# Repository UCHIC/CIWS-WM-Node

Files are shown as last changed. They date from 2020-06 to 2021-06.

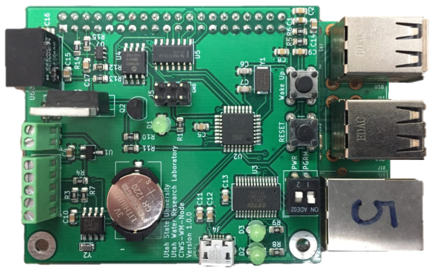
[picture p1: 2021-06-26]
Hardware/PCB_Design/DevicePicturePCB.png

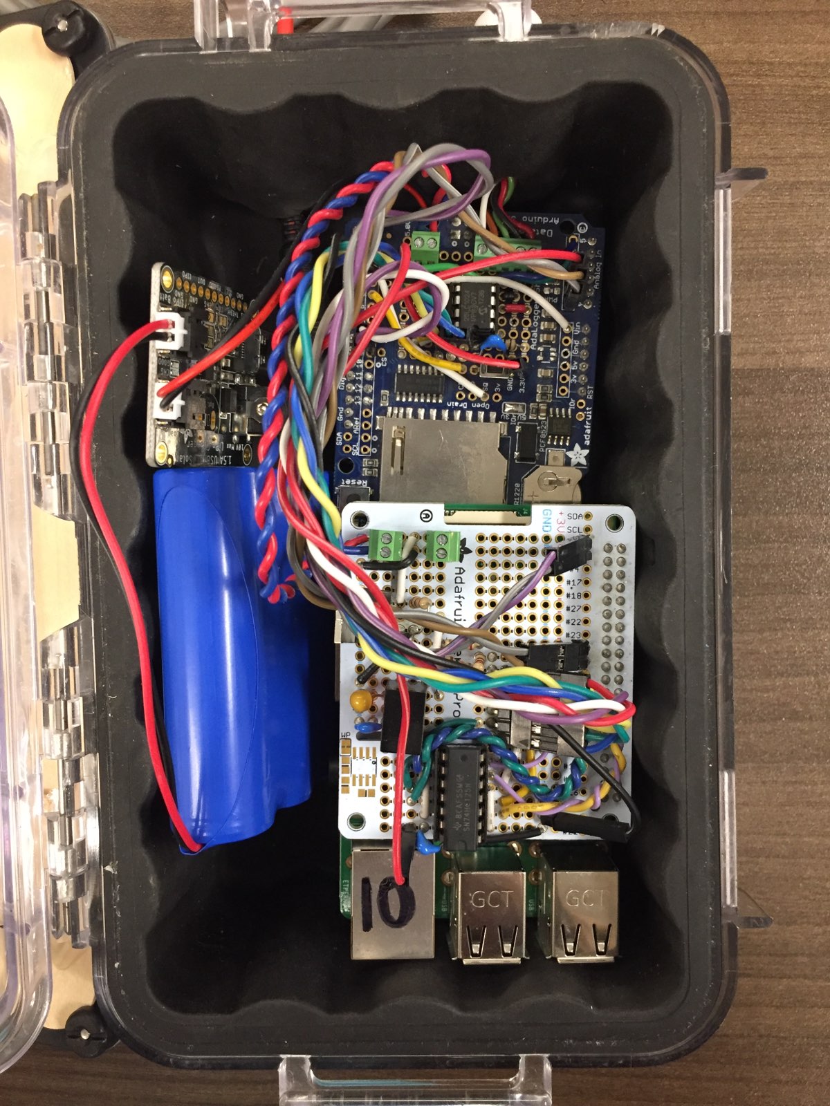
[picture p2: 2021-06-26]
Hardware/Off-The-Shelf/DevicePicturePrototype.jpg

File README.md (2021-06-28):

# CIWS-WM-Node

This repository contains hardware and software designs for a computationally-enabled water meter datalogger. The hardware is made up of two parts. One part is a Raspberry Pi single board computer that serves as the computational resource. The Raspberry Pi is coupled with a data acquisition device that is based on an Arduino Pro and is similar to our simplified datalogger for magnetically-driven residential water meters (See [UCHIC/CIWS-MWM-Logger](https://github.com/UCHIC/CIWS-MWM-Logger)).

The data acquisition device is primarily responsible for processing magnetometer sensor data and storing flow data from the water meter. Secondarily, it controls power to the Raspberry Pi in order to conserve battery life and reduce overall power consumption. Once powered, the Raspberry Pi retreives the flow data and processes it to compute useful summaries of water use, identify water end-uses, or execute other user-defined computational code.

## Structure of this Repository

The 'Firmware' directory contains the firmware for the microcontroller-based data acquisition device, or Datalogger.

The 'Software' directory contains the software for the Raspberry Pi.

The 'Hardware' directory contains hardware design information, including a design and instructions for assembling a Node from off-the-shelf components as well as a printed circuit board (PCB) design and instructions for manufacturing them.

The 'Docs' directory contains documentation.

This device is still under active development.

## Cyberinfrastructure for Intelligent Water Supply (CIWS) 

CIWS is a project funded by the U.S. National Science Foundation to develop cyberinfrastructure for smart water metering and high resolution water-use data collection. We are developing systems for high resolution residential water consumption data collection, processing, and analysis.

## Sponsors and Credits


This work was supported by National Science Foundation Grant [CBET 1552444](https://www.nsf.gov/awardsearch/showAward?AWD_ID=1552444). Any opinions, findings, and conclusions or recommendations expressed in this material are those of the author(s) and do not necessarily reflect the views of the National Science Foundation.

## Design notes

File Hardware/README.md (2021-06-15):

# WM-Node Hardware

This directory contains design files pertaining to the WM-Node datalogging device separated into two directories.

## PCB Design
The directory PCB_Design contains design files in KiCad for a printed circuit board which hosts all of the required components to transform a Raspberry Pi into a WM-Node device. The design files are generated using KiCad 5.

## Off-the-shelf Parts
The directory off-the-shelf parts contains a list of all the parts necessary to create a computaional node using off the shelf parts. This directory also contains instructions and diagrams for contructing the computational node.

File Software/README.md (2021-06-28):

## Instructions for Configuring a Raspberry Pi

NOTE: Only the Raspberry Pi 3 Model B V1.2 has been verified to work, although newer models should work as well.

1. Connect your Raspberry Pi to the internet. 
2. Type `sudo apt-get update` into the command line and hit enter. This updates software packages available on your pi.
3. Type `sudo apt-get install git` into the command line and hit enter. This installs git onto your pi.
4. Type `git clone https://github.com/UCHIC/CIWS-WM-Node.git` into the command line and hit enter. Using git, this clones this repository onto your pi.
5. Type `mv CIWS-WM-NODE/Software/ Software` into the command line and hit enter. This moves the Software directory into your home directory.
6. Type `cd Software` into the command line and hit enter. This changes the Software directory to your working directory.

From the `Software` directory, run the following commands:
```
chmod +x setup.sh
sudo ./setup.sh
```
At a minimum, be sure to `set-timer-resolution` before attempting to log.

You can now use the `Logger` module in Python. Note that this was built with Python 3.7.</br></br>
The following dependencies should be automatically installed by running `setup.sh` on the Raspberry Pi, assuming the Raspberry Pi is connected to the internet.
```
python3-dev
python3-smbus
wiringpi
python3-requests
python3-pandas
python3-seaborn
pyhton3-sklearn
```

## Software Overview

Most of the Software functionality of the WM-Node device is described in the file `logger.c`. The C code is compiled as a Python module by the script `setup.sh`, and is used in the Python scripts in this directory.

### Files:
- `LoggerAutoRun.py`: Runs on every power up.
- `LoggerShell_CLI.py`: User interfaces for the datalogger.
- `piHandler.py`: Handles the functions primarily used by the pi.
- `arduinoHandler.py`: Handles functions used to commmunicate with arduino.
- `README.md`: This file.
- `bashrc`: Configuration file for the Raspberry Pi.
- `cmdline.txt`: Configuration file for the Raspberry Pi.
- `config.txt`: Configuration file for the Raspberry Pi.
- `logger.c`: Defines all of the functions use in the `Logger*` python scripts.
- `rc.local`: Configuration file for the Raspberry Pi.
- `setup.py`: Builds Python module Logger from `logger.c`.
- `setup.sh`: Sets up Raspberry Pi device using the files in this directory.
- `uuidcopy.c`: Copies the value for the field `root=PARTUUID=` from the original `cmdline.txt` and stores it in the new `cmdline.txt`.

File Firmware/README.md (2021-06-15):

This folder contains the source code for the firmware running on the ATmega328p microcontroller in the folder `Computational_Firmware`. It was developed using Arduino IDE version 1.8.9, though there are very few actual Arduino Libraries used (in order to save on performance).

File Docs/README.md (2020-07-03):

# Documentation
This directory contains documents describing the hardware, software, and firmware of the CIWS-WM-Node datalogging device.
## Hardware
The hardware documentation covers the basic system architecture and functional overview. Electrical diagrams and hardware design files are located in the `Hardware` directory.
## Firmware
The firmware documentation covers the code written for the AVR microcontroller portion of the device.
## Software
The software documentation covers the code written for the Raspberry Pi embedded computer connected to the device.

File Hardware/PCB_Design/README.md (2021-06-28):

# Manufacturing
This folder contains all the files necessary for manufacturing a printed circuit board (PCB) version of the CIWS-WM-Node. The PCB contains everything needed to interface with a Raspberry Pi computer and magnetometer sensor to collect and process data.

The `.pro` and `.sch` files are the board layout and schematic respectively. Use these two files with the `.kicad_pcb` file to view the design in kicad.

The `.csv` file and `.zip` files are used for manufaturing the devices. The `.zip` file contains the drill file, gerber files, assembly drawings, and position files. The `.csv` is a list of components used on the device. 

# Instructions for setting up the PCB After Manufacture

1. Remove the jumper on the `EEPROM Power` pins.
2. Connect the micro usb port on the PCB to your computer using a USB cable and turn the `PWR` switch on the PCB ON.
3. Connect your computer to the 6 header pins on the PCB with an AVR in-system programmer (ISP). Make sure to plug in the ribbon cable the right direction. A suitable AVR ISP is referenced in the link below.
4. Open up the code in the `Firmware` directory from this repository using the Arduino IDE and click on `Tools`. Select `Arduino Pro or Pro mini` as the board, `Atmega328P (3.3V 8MHZ)` as the processor, and `AVR ISP` as the programmer.
5. While still in the Arduino IDE, click `Burn Bootloader`. Wait for it to finish.
6. Unplug the AVR ISP from the PCB and turn the `PGRM` switch on the PCB ON.
7. In the `Tools` menu of the Arduino IDE, select the serial port connected to the micro usb port. If you are unsure which one is correct you can unplug the USB cable and see which one disappears. Reconnect the USB cable and select that one.
8. In the Arduino IDE, click `Upload`. This unploads the code onto the ATMEGA328P chip.
9. Turn the `PWR` and `PRGM` switches off on the PCB. 
10. Put the jumper back on the `EEPROM Power` pins on the PCB. 

Once these steps are complete, the PCB is ready to be snapped onto the header of a Raspberry Pi for use.

A suitable AVR ISP: https://www.pololu.com/product/3172

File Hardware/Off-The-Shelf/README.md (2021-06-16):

# Off-the-shelf Parts

This directory contains files describing the construction of a WM-Node device using off-the-shelf parts obtainable from electronics suppliers such as Mouser, Sparkfun, and Adafruit.

The BuildInstructions.txt file gives instructions for setting up the adafruit datalogger shield. 

PrototypeWiringGuide.png gives a diagram for how to wire the pi and arduino together.

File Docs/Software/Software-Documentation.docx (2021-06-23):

CIWS-WM-Node Datalogger

Software Documentation

Software ver. 1.0.0

# Project Organization

  The CIWS-WM-Node software is comprised of the following files:
- LoggerAutoRun.py
- arduinoHandler.py
- piHandler.py
- LoggerShell_CLI.py
- logger.c
- setup.py
- setup.sh

The functions which interact with the Raspberry Pi GPIO peripherals are written in C code in logger.c. Using Python's API (available from Python.h), these C functions are wrapped up as a Python module called Logger, which is used in arduinoHandler.py. The software can be set up on the Raspberry Pi by running setup.sh, which configures the Raspberry Pi and calls setup.py, which compiles logger.c.

arduinoHandler.py Is a wrapper module for logger.c. It handles the communication of the pi with the microcontroller and EEPROM. It also handles the initialization of the SPI, UART, and GPIO pins. Pins 24 and 25 on the raspberry pi are set by this module to indicate that the EEPROM is being read and that the pi is on respectively.

LoggerAutoRun.py is run automatically whenever the Raspberry Pi is powered on. It is responsible for retrieving data from the EEPROM. It will also shut down the Raspberry Pi if the data buffer is full or it is midnight (in other words, if it was not turned on by a user).

piHandler.py handles the functionality of the pi. This includes the storage and retrieval of settings data. It also handles the analysis, storage, and transmission of both raw data and data resulting from the computations of raw data.

As the previous paragraphs suggest, with the exception of LoggerAutoRun.py, these scripts are run by LoggerShell_CLI.py. In fact, users should not run any other script than LoggerShell_CLI.py, which is run automatically when the user logs in. This script provides a user interface as a 'shell' around the functionality of the datalogger.

# GPIO Functions: logger.c

The code in logger.c comprises the Logger module used in the other Python scripts. There are 9 functions in this file:

- init
- initPins
- bufferMax
- setRomBusy
- setPowerGood
- loadData
- reportSwap
- setRomFree
- setPowerOff

These functions mainly deal with GPIO and file I/O operations using the following libraries:

- wiringPi.h
- wiringPiSPI.h
- wiringSerial.h

The following sections describe the individual functions in this file.

## Initializing the Module: init()

The function init initializes the wiringPi GPIO library, the wiringPi SPI library, and the wiringPi Serial library. The SPI module is initialized to communicate at 2 MHz, and the Serial module is initialized to communicate at 9600 Baud.

## Initializing the GPIO pins: initPins()

This function sets up the initial values of the GPIO pins. There are two GPIO pins this function initializes:

- ROM_BUSY (Broadcom GPIO 24)
- POWER_GOOD (Broadcom GPIO 25)

ROM_BUSY and POWER_GOOD are both initialized as logic low (0 V).

## Read Maximum Buffer Size: bufferMax()

This function simply returns the variable BUFFER_MAX. This value determines the amount of data that the Raspberry Pi reads from the EEPROM chip.

## Request EEPROM: setRomBusy()

This function sets the ROM_BUSY pin HIGH, which tells the microcontroller that the Raspberry Pi is reading the EEPROM. The microcontroller yields the EEPROM in CERTAIN SITUATIONS:

1. The Raspberry Pi was just activated
2. The Raspberry Pi instructed the microcontroller to stop a logging session

The microcontroller will not honor this request in any other situations.

## Report Power On: setPowerGood()

This function sets the POWER_GOOD pin HIGH, which tells the microcontroller that the Raspberry Pi has successfully powered on.

## Read Data from EEPROM: loadData()

This function reads data from the EEPROM chip. The function allocates an array to hold the EEPROM data. The function then calls a SPI transaction, and data gets transferred from the EEPROM chip to the data array.

## Swap Report with Microcontroller: reportSwap()

    This function swaps "report" data with the Arduino. This data consists of the following:

Data Field (Bytes) | Name | Description
0 | Years | Current year
1 | Months | Current month
2 | Days | Current day
3 | Hours | Current hour
4 | Minutes | Current minute
5 | Seconds | Current second
6 | Previous Pulses | Pulses in the previous logging sample period
7 | Total Pulses 0 | Total pulses over logging session (byte 0)
8 | Total Pulses 1 | Total pulses over logging session (byte 1)
9 | Total Pulses 2 | Total pulses over logging session (byte 2)
10 | Logging | Boolean: Is the device logging or not?

The data swap is done over a serial UART bus. The data messages are interlaced; in other words, the Raspberry Pi sends one byte, and the Arduino sends the corresponding byte. The Raspberry Pi can overwrite the data by sending any data value other than 0xFF, or 255. 255 (0xFF) is used by the Raspberry Pi to read the data.

## Release EEPROM: setRomFree()

    This function simply sets the ROM_BUSY pin low, signaling to the Arduino that the Raspberry Pi has finished reading the EEPROM.

## Report Power Off: setPowerOff()

    This function sets the POWER_GOOD pin low, signaling to the Arduino that the Raspberry Pi is shutting down. The Arduino will cut power to the Raspberry Pi 12 seconds after receiving this information.

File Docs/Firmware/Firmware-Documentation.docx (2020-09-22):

CIWS-WM-Node Datalogger

Firmware Documentation

Firmware ver. 1.0.0

# Project Organization

  The CIWS-WM-Node Datalogger project is organized using the standard approach using header files and source files, applied to an Arduino IDE environment. For those unfamiliar, C/C++ code is separated into header files and source files. The following example aims to make it clear why this is the case.
  Consider the following C code:
  int main()
  {
  int a = 2;
    int b = a * 4;
    printf(“The result is %d\n”, b);
    int c = b * 4;
    printf(“The result is %d\n”, c);
    return 0;
  }
  Obviously, this is a trivial example to illustrate how much more complex code is handled in this project. This code can be much more modular (and readable) by introducing a function:
  int times4(int input)
  {
  return input * 4;
  }

int main()

{

int a = 2;

int b = times4(a);

printf(“The result is %d\n”, b);

int c = times4(b);

printf(“The result is %d\n”, c);

return 0;

}

The code is now more readable and modular, but now the main() function is at the bottom of the file (and it has to be, otherwise the function times4() would not be recognized in main(). Fortunately, programmers are good at finding ways around problems. The following code listing works just as well as the previous example:

  int times4(int input);

int main()

{

int a = 2;

int b = times4(a);

printf(“The result is %d\n”, b);

int c = times4(b);

printf(“The result is %d\n”, c);

return 0;

}

  int times4(int input)
  {
  return input * 4;
  }
  Now, the main() function is much closer to the top of the file, making it easy to find the program’s starting point. The main() function recognizes the times4() function because it’s declared above main() using what’s called a function prototype, while the rest of times4() is defined below main(). This works really well for a handful of functions, but defining every function in one file becomes a mess in a project like the CIWS-MWM firmware. To counter this, two new files are created: times4.h and times4.cpp. The function prototype goes in times4.h, and the function definition goes in times4.cpp, leaving the file containing main() nice and clean:
  #include “times4.h”

int main()

{

int a = 2;

int b = times4(a);

printf(“The result is %d\n”, b);

int c = times4(b);

printf(“The result is %d\n”, c);

return 0;

}

Again, though this example seems trivial, it is a very good way to organize a large firmware project like CIWS-MWM. The aim of this section was to illustrate why the project is organized the way it is.

# Main Loop: Computational_Firmware.ino

The file Computational_Firmware.ino is the program’s starting point. All Arduino projects have a .ino file. Ours contains four functions:

- void setup()
- void loop()
- void INT0_ISR()
- void INT1_ISR()

The functions setup() and void() in the .ino file are actually called in the following manner:

int main()

{
setup();

while(1)

{

loop();

}

}

This way, setup() is called once, and loop() is called repeatedly until the microcontroller is reset. A flowchart of this process is shown here:

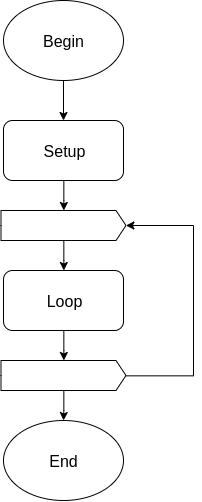
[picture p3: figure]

The setup() function does the following:

- Initializes the GPIO pins and peripherals
- Initializes the system state data structure
- Initializes the magnetometer
- Initializes the real-time clock
- Sets up the magnetometer and real-time clock interrupt handlers
- Stops the clock for all unused peripherals

A flow chart of the setup() function is shown on the next page.

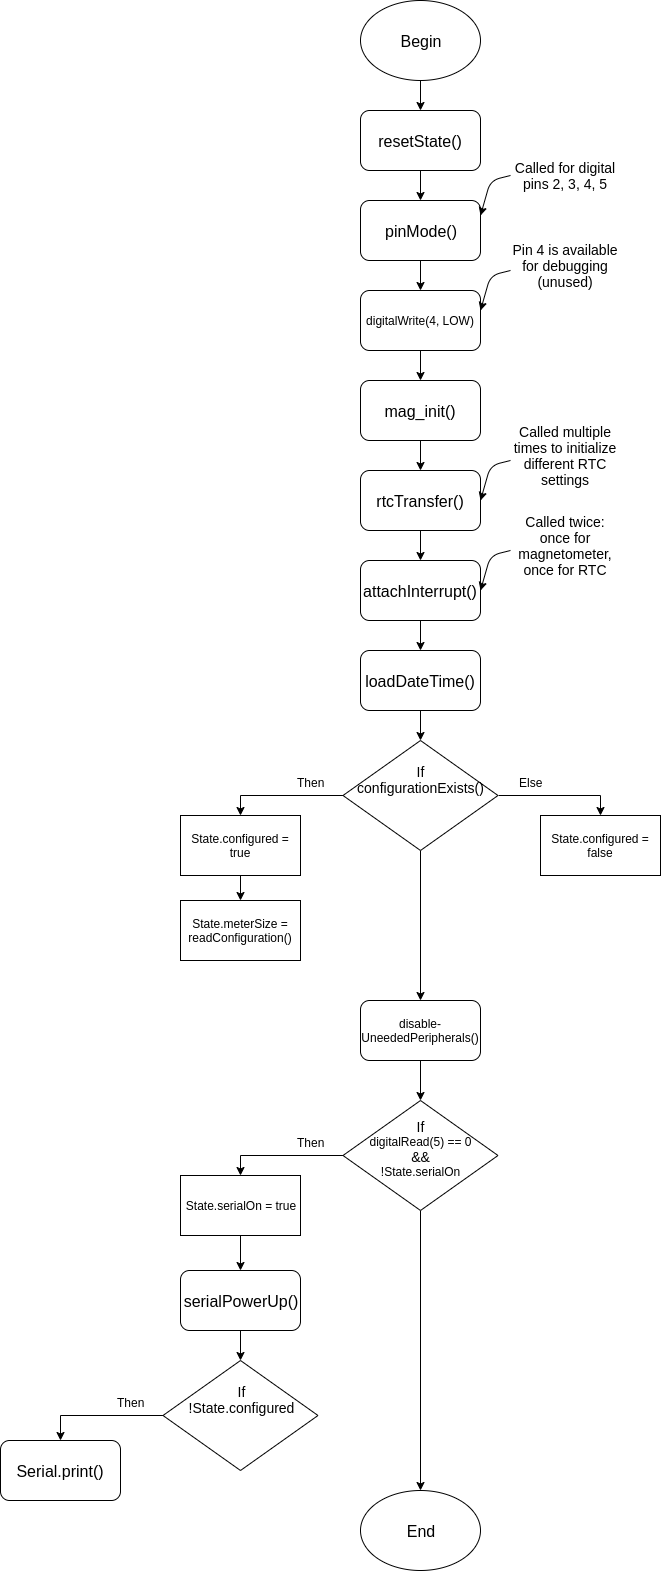
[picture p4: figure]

The loop() function is the datalogger firmware’s main loop, and performs the following actions:

1. Check if the Raspberry Pi should be activated
2. Run the serial communication between the datalogger and the Raspberry Pi
3. Monitor signals from the Raspberry Pi
4. Check if four seconds are up
5. Check if magnetometer data is ready
6. Process incoming data to count peaks

A flowchart of the loop() function is shown on the next page.

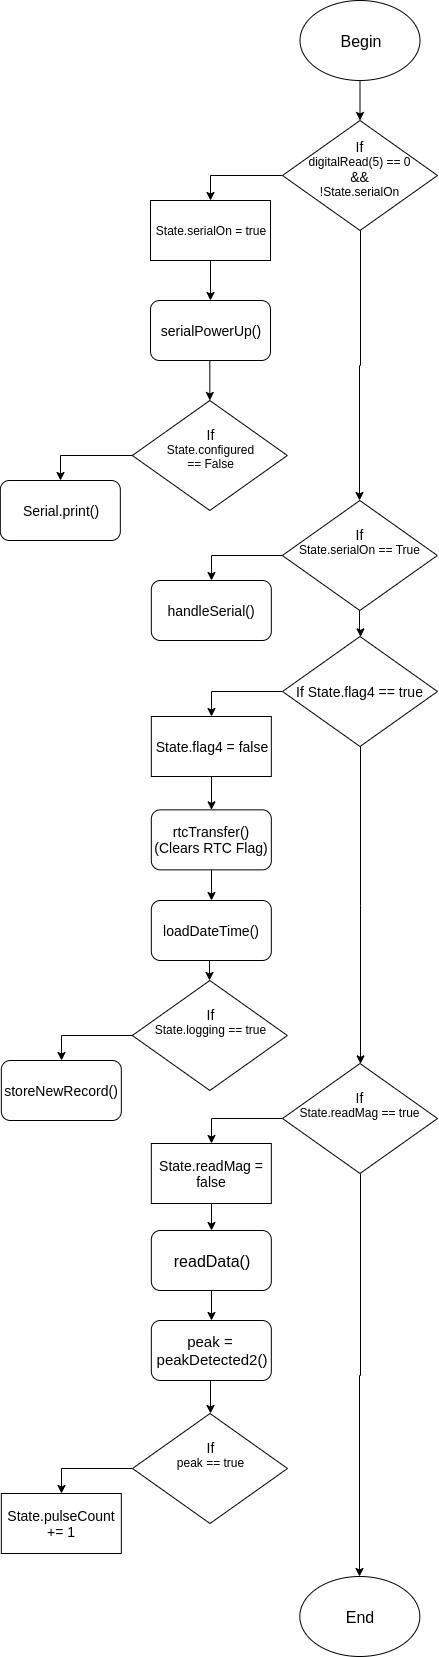
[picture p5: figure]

The functions INT0_ISR() and INT1_ISR() are both interrupt service routines. For those unfamiliar with interrupts, an interrupt service routine is a function executed when an event in hardware occurs. INT0_ISR() code executes when the voltage on digital pin 2 transitions from low to high, and INT1_ISR() code executes when the voltage on digital pin 3 transitions from high to low.

The voltage signal on digital pin 2 is controlled by the magnetometer. When the magnetometer has new data ready to report, it sets the voltage on pin 2 high, causing INT0_ISR() to execute.

The voltage signal on digital pin 3 is controlled by the real time clock. When four seconds have elapsed, the real time clock sets the voltage on pin 3 low, causing INT1_ISR() to execute.

Both interrupt service routines simply set a flag to true. The main loop checks these flags, and if they are set, responds accordingly. This is good practice; interrupt service routines need to be kept as short as possible.

# System State: state.h and state.cpp

  These files define two C/C++ structs, State and SignalState.
  State keeps track of several important values:
- byte pulseCount – The number of pulses in the current sample period.
- byte lastCount – The number of pulses in the previous sample period.
- unsigned int totalCount – The number of pulses since logging started.
- unsigned long recordNum – The record number of the current sample period.
- bool logging – Boolean flag: True if the device is logging, false if it is not.
- bool flag4 – Boolean flag: True if four seconds has passed, false if not.
- bool serialOn – Boolean flag: True if serial interface is active, false if it is not.
- bool SDin – Boolean flag: True if an SD card has been initialized, false if not.
- bool readMag – Boolean flag: True if magnetometer data is ready, false if it is not.
- char meterSize – Stores the meter size, used to compute water flow.
- bool configured – Boolean flag: True if valid configuration data exists in memory.
- char filename[13] – Stores the current filename.

This State struct is initialized using the function void resetState(volatile State_t* State). The pulse counts are initialized to zero, the record number is initialized to one, and the boolean flags are initialized to false.

SignalState keeps track of values used for processing the magnetometer signal. A few values are left over from an older signal processing algorithm. These are noted, and will be removed in a future release.

- float x[2] = {0, 0}; – Input signal from the magnetometer.
- float s = 0; - From old algorithm.
- float sf[2] = {0, 0}; - From old algorithm.
- float a = 0.95; - DC Removal filter pole.
- float y[2] = {0, 0}; - Output signal from DC Removal filter.
- float offset = -0.005; - From old algorithm.
- bool slopeWasPositive = false; - From old algorithm.
- bool slopeIsPositive = false; - From old algorithm.
- bool triggered = false; - Boolean flag for software-based schmitt trigger.

The use of these values is detailed in the next section, Peak Detection.

# Peak Detection: detectPeaks.h and detectPeaks.cpp

These files define the function bool peakDetected(volatile SignalState_t* signalState)

The function peakDetected() is responsible for detecting peaks corresponding to water flow in the signal read by the magnetometer. Before going over the code, it is crucial to understand the filtering algorithm implemented by the code.

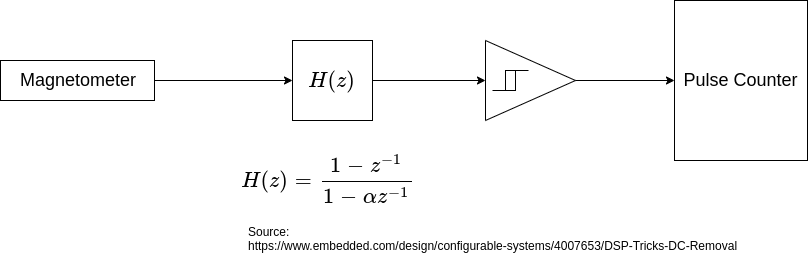
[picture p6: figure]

The function peakDetected() implements the two middle blocks of the above diagram. The block H(z) removes the signal’s DC offset. This centers the signal at zero, which permits a simple peak-detecting algorithm called a software schmitt trigger, the triangular block in the diagram.

The schmitt trigger watches for the signal to cross its high and low thresholds. When the signal crosses the high threshold, the schmitt trigger will count it as a peak, but will not count any other high-threshold crossing as a peak until the signal crosses the low threshold. This ensures that noise in the magnetometer’s signal cannot be counted as extra peaks. This peak detection is implemented in the following way:

Begin:

/** H(z) **/

y[n] = a * y[n - 1] + x[n] - x[n - 1]

/** Schmitt Trigger **/

If triggered:

If y[n] < -1:

triggered is false

If not triggered:

If y[1] > 1:

triggered is true

return peak = true

End

  A C/C++ struct called SignalState stores the current input sample (x[n]), the previous input sample (x[n - 1]), and the previous output sample (y[n – 1]). SignalState also holds a and triggered. Threshold values for the Schmitt Trigger are declared inside the function peakDetected(). This information is all that is necessary to detect if a peak is occurring in the magnetometer’s signal. SignalState is defined in the file state.h.
  The value a is the pole of H(z). For this filter, it is desirable for the pole to be close to, but not equal to, one. For any digital filter, a pole greater than or equal to one causes instability.

This function is only called once every time a data sample is collected from the magnetometer.

# Magnetometer: magnetometer.h and magnetometer.cpp

The following functions are defined in magnetometer.cpp and magnetometer.h:

1. bool mag_init()
2. void read_mag(int8_t* data)
3. void mag_transfer(int8_t* data, uint8_t reg, uint8_t numBytes, uint8_t RW)
4. readData(volatile SignalState_t* SignalState)
5. initializeData(volatile SignalState_t* SignalState)

These functions are responsible for the initialization and reading of an LIS3MDL magnetometer. Above, they are listed in order of appearance, but in the following sections, they will be covered in order from low-level to high-level functionality.

The function mag_transfer() takes an array of data, a register number, the length of the array of data, and a read/write flag as input, and is responsible for writing data and reading data to and from the magnetometer. Most of the time, data will be read from the magnetometer, but data does get written to the magnetometer when initialized on startup. The data is read and written via an I²C serial bus, and the Arduino IDE’s Wire library is used for I²C communication.

The function mag_init() does not take any input, and is responsible for initializing the magnetometer when the datalogger is started up. It utilizes the function mag_transfer() to write initialization data to the magnetometer. The following table lists the data written to each of the magnetometer’s control registers, along with the behavior due to the data written.

Register | Data | Behavior
Control Register 1 | 0x32 | - Temperature sensor disabled - X-Axis in Medium Performance Mode - Y-Axis in Medium Performance Mode - Output data rate ~560-570 Hz - Self-test disabled
Control Register 2 | 0x00 (Default) | - Output data scaled to ⁺/- 4 gauss
Control Register 3 | 0x00 | - Low-power mode disabled - Sample: Continuous-conversion mode
Control Register 4 | 0x04 | - Z-Axis in Medium Performance Mode
Control Register 5 | 0x80 | - Set FAST READ

More data for these registers can be found in section 7 of the LIS3MDL datasheet. The key takeaway from this table is that the magnetometer is set to a high output data rate, medium performance mode for all axes, reads on a ⁺/- 4 gauss scale, and does what the datasheet refers to as FAST READ. FAST READ means that only the top half of the two-byte data sample are reported by the magnetometer. This is beneficial in part because most signal noise is contained in the lower half byte; however, the resulting signal is less smooth, so a signal consisting of two-byte data samples is being considered for a future version. The combination of a fast output data rate and all axes set to medium performance mode results in an output data rate of about 570 Hz (measured experimentally).

The function read_mag() takes an array of data, which it will populate with data from the magnetometer by calling mag_transfer(data, OUT_X_H, 3, MAG_READ); This reads the data output of the X, Y, and Z axes of the magnetometer.

The function readData() takes a SignalState structure, described previously. The function calls read_mag() and stores the output byte from the x axis in the SignalState structure as a floating point number, allowing it to be processed by the functions in detectPeaks.cpp.

The function initializeData() actually does the same thing as the function readData(). They are likely to be merged in a future version.

# Real Time Clock: RTC_PCF8523.h and RTC_PCF8523.cpp

The following functions are defined in RTC_PCF8532.h and RTC_PCF8523.cpp:

- byte rtcTransfer(byte reg, byte flag, byte value)
- void registerDump()
- void loadDateTime(Date_t* Date)

These files also define a list of hexadecimal addresses for the RTC’s registers and a Date structure, which holds the current year, month, day, hour, minute, and second (updated every four seconds).

The function rtcTransfer() is responsible for transferring data to the RTC, and takes an eight-bit register number, a read/write flag, and an eight-bit value to write. This function utilizes the Arduino IDE’s Wire library for I²C communication with the RTC.

The function registerDump() prints the data in each register to a serial terminal, and is used to verify the contents of each RTC register.

The function loadDateTime() reads all of the RTC’s date and time registers, and stores the resulting data in a Date_t structure. This function is called every four seconds.

The RTC is initialized in Firmware.ino using the following calls to rtcTransfer():

rtcTransfer(reg_Tmr_CLKOUT_ctrl, WRITE, 0x3A);

rtcTransfer(reg_Tmr_A_freq_ctrl, WRITE, 0x02);

rtcTransfer(reg_Tmr_A_reg, WRITE, 0x04);

rtcTransfer(reg_Control_2, WRITE, 0x02);

rtcTransfer(reg_Control_3, WRITE, 0x80);

These calls are likely to be combined into a single function in a future release. Below is a table detailing what each register configuration does:

Register | Data | Behavior
Timer CLOCKOUT Control | 0x3A | - Disable 1-second clock output - Configure Timer A as countdown timer. - Disable Timer B
Timer A Frequency Control | 0x02 | - Use a 1 Hz source clock for Timer A countdown.
Timer A Register | 0x04 | - Set Timer A to countdown from 4 (4-second timer).
Control Register 2 | 0x02 | - Clears any interrupt flags - Enables Timer A Countdown Interrupt - Disables all other interrupts in Control Register 2
Control Register 3 | 0x80 | - Enables battery switch-over function in standard mode - Clears any interrupt flags - Disables interrupts in Control Register 3

# Configuration Data: configuration.h and configuration.cpp

The ATmega328p microcontroller used for this datalogger has a small chunk of Electrically Erasable Programmable Read-Only Memory, or EEPROM, in which datalogger configuration data is stored. 15 bytes of EEPROM are used, laid out in the following organization:

Address | Data
0x0 | Site Number (100’s Place)
0x1 | Site Number (10’s Place)
0x2 | Site Number (1’s Place)
0x3 | Meter Size
0x4 | Datalogger ID (100’s Place)
0x5 | Datalogger ID (10’s Place)
0x6 | Datalogger ID (1’s Place)
0x7 | File Number (1000’s Place)
0x8 | File Number (100’s Place)
0x9 | File Number (10’s Place)
0xA | File Number (1’s Place)
0xB | Checksum 0
0xC | Checksum 1
0xD | Checksum 2
0xE | Checksum 3

Three functions are used in relation to this configuration data:

- bool configurationExists();
- uint8_t readConfiguration(uint8_t segment);
- void writeConfiguration(uint8_t segment, char data);

The function configurationExists() checks the EEPROM for valid configuration data by reading the checksum bytes in addresses 0xB – 0xE using the readConfiguration() function. It then calculates two different values: Checksum 0 + Checksum 1 and Checksum 2 + Checksum 3. If they both equal 0xFF, then the configuration data is considered present and valid.

The function readConfiguration() first waits for completion of any EEPROM writes in progress. It then loads a read address into the EEPROM Address Register (EEAR) and initiates an EEPROM Read operation. It then returns the data in EEDR, the register in which data read from the EEPROM is stored.

The function writeConfiguration() takes both an address and a data byte. It first waits for completion of any EEPROM writes in progress. It loads a read address into the EEAR, loads data into the EEDR, enables EEPROM writes, and starts an EEPROM write.

# Power Reduction: powerSleep.h and powerSleep.cpp

The MWM Datalogger is a battery-powered logger, and as such, it is crucial that energy is saved in every possible part of the device to prolong the possible logging period. This is done in part with the functions listed here:

- void enterSleep();
- void disableUnneededPeripherals();
- void twiPowerUp();
- void twiPowerDown();
- void serialPowerUp();
- void serialPowerDown();
- void SDPowerUp();
- void SDPowerDown();

If you’ve been examining the source code, you’ve no doubt encountered these functions. That’s because most peripherals are powered down on start-up, and are only powered on when needed. These functions make use of functions from <avr/sleep.h> and <avr/power.h>. These libraries are available through the Arduino IDE, or by installing avr-libc. Power-up and power-down are accomplished by activating and deactivating the clock, respectively. When a peripheral receives no clock signal, it does nothing, and is effectively powered off.

The function enterSleep() puts the microcontroller into a standby mode in which very little power is consumed. The mode SLEEP_MODE_STANDBY is selected, sleep is enabled, and the microcontroller is put to sleep. The program is halted at this point. On wake-up, sleep is disabled and the function returns control. Use of this function causes data samples to be recorded incorrectly, and as such is unused. This function will be put in use again once the error is corrected.

The function disableUnneededPeripherals() is called on startup in Firmware.ino. This function first disables the ADC by writing 0x00 to the ADCSRA register. Once this is done, this function calls the following functions from <avr/power.h>:

power_adc_disable();

power_timer0_disable();

power_timer1_disable();

power_timer2_disable();

power_twi_disable();

power_usart0_disable();

power_spi_disable();

This deactivates the clock to all of the above peripherals.

All of these peripherals are turned on again when needed using the corresponding PowerUp() function:

- I²C bus: twiPowerUp()
- Serial Port: serialPowerUp()
- SD Interface (SPI): SDPowerUp()

Each PowerUp() function is similar:

I²C Bus:

void twiPowerUp(){

power_twi_enable(); // From <avr/power.h>

_delay_us(1); // Pause execution for peripheral to start

Wire.begin(); // Initialize Arduino’s Wire library

_delay_us(1); // Pause execution for peripheral to start

return;

}

Serial Port:

void serialPowerUp(){

power_usart0_enable(); // From <avr/power.h>

_delay_ms(10); // Pause execution for peripheral to start

Serial.begin(9600); // Initialize Arduino’s Serial library

_delay_ms(10); // Pause execution for peripheral to start

Serial.print(F(">> Logger: Logger ready.\n>> User: "));

return;

}

SD Interface (SPI):

void SDPowerUp(){

power_spi_enable(); // From <avr/power.h>

return;

}

All of these peripherals are turned off again when needed using the corresponding PowerDown() function:

- I²C bus: twiPowerDown()
- Serial Port: serialPowerDown()
- SD Interface (SPI): SDPowerDown()

All of the PowerDown() functions simply call their respective power_xxx_disable() function from the <avr/power.h> library (as seen in disableUnneededPeripherals()).

# Table of Functions and Structs (Lexicographical Order)

Function or Struct Name | Declaration | Definition
bcdtobin() | storeNewRecord.h Line 5 | Firmware.ino Lines 406 - 417
cleanSD() | handleSerial.h Line 20 | handleSerial.cpp Lines 270 - 324
configurationExists() | configuration.h Line 25 | configuration.cpp Lines 3 - 25
createHeader() | handleSerial.h Line 35 | handleSerial.cpp Lines 1028 - 1065
Date_t | RTC_PCF8523.h Lines 44 - 53 | RTC_PCF8523.h Lines 44 - 53
disableUnneededPeripherals() | powerSleep.h Line 8 | powerSleep.cpp Lines 58 - 71
ejectSD() | handleSerial.h Line 23 | handleSerial.cpp Lines 410 - 426
enterSleep() | powerSleep.h Line 7 | powerSleep.cpp Lines 21 - 37
exitSerial() | handleSerial.h Line 22 | handleSerial.cpp Lines 381 - 390
getInput() | handleSerial.h Line 31 | handleSerial.cpp Lines 878 - 885
getNestedInput() | handleSerial.h Line 32 | handleSerial.cpp Lines 904 - 919
handleSerial() | handleSerial.h Line 18 | handleSerial.cpp Lines 53 - 143
INT0_ISR() | Firmware.ino Lines 230 - 234 | Firmware.ino Lines 230 - 234
INT1_ISR() | Firmware.ino Lines 245 - 248 | Firmware.ino Lines 245 - 248
incrementFileNumber() | handleSerial.h Line 37 | handleSerial.cpp Lines 1088 - 1106
initializeData() | magnetometer.h Line 78 | magnetometer.cpp Lines 320 - 331
initSD() | handleSerial.h Line 25 | handleSerial.cpp Lines 483 - 499
listFiles() | handleSerial.h Line 26 | handleSerial.cpp Lines 501 - 545
loadDateTime() | RTC_PCF8523.h Line 57 | RTC_PCF8523.cpp Lines 137 - 170
loop() | Firmware.ino Lines 150 - 220 | Firmware.ino Lines 150 - 220
mag_init() | magnetometer.h Line 72 | magnetometer.cpp Lines 85 - 167
mag_transfer() | magnetometer.h Line 74 | magnetometer.cpp Lines 231 - 258
nameFile() | handleSerial.h Line 36 | handleSerial.cpp Lines 1067 - 1086
peakDetected2() | detectPeaks.h Line 15 | detectPeaks.cpp Lines 98 - 126
printConfig() | handleSerial.h Line 34 | handleSerial.cpp Lines 973 - 1009
printHelp() | handleSerial.h Line 24 | handleSerial.cpp Lines 441 - 460
printWater() | handleSerial.h Line 33 | handleSerial.cpp Lines 921 - 971
RTC_Doctor() | handleSerial.h Line 30 | handleSerial.cpp Lines 547 - 697
readConfiguration() | configuration.h Line 26 | configuration.cpp Lines 27 - 34
readData() | magnetometer.h Line 77 | magnetometer.cpp Lines 284 - 295
read_mag() | magnetometer.h Line 73 | magnetometer.cpp Lines 189 - 194
registerDump() | RTC_PCF8523.h Line 56 | RTC_PCF8523.cpp Lines 76 - 101
resetState() | state.h Line 39 | state.cpp Lines 3 - 17
rtcTransfer() | RTC_PCF8523.h Line 55 | RTC_PCF8523.cpp Lines 36 - 55
SDPowerDown() | powerSleep.h Line 14 | powerSleep.cpp Lines 192 - 197
SDPowerUp() | powerSleep.h Line 13 | powerSleep.cpp Lines 173 - 178
SignalState_t | state.h Lines 26 - 37 | state.h Lines 26 - 37
State_t | state.h Lines 8 - 22 | state.h Lines 8 - 22
serialPowerDown() | powerSleep.h Line 12 | powerSleep.cpp Lines 154 - 159
serialPowerUp() | powerSleep.h Line 11 | powerSleep.cpp Lines 131 - 140
setConfiguration() | handleSerial.h Line 19 | handleSerial.cpp Lines 176 - 248
setup() | Firmware.ino Lines 105 - 148 | Firmware.ino Lines 105 - 148
startLogging() | handleSerial.h Line 27 | handleSerial.cpp Lines 718 - 757
stopLogging() | handleSerial.h Line 28 | handleSerial.cpp Lines 778 - 792
storeNewRecord() | storeNewRecord.h Line 4 | Firmware.ino Lines 307 - 360
twiPowerDown() | powerSleep.h Line 10 | powerSleep.cpp Lines 108 - 113
twiPowerUp() | powerSleep.h Line 9 | powerSleep.cpp Lines 86 - 94
updateDateTime() | handleSerial.h Line 29 | handleSerial.cpp Lines 808 - 864
viewDateTime() | handleSerial.h Line 21 | handleSerial.cpp Lines 340 - 362
writeConfiguration() | configuration.h Line 27 | configuration.cpp Lines 36 - 45

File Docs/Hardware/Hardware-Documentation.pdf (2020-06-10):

# CIWS-WM-Node

## Hardware Documentation

## Overview

The WM-Node datalogger consists of the following main components:
1. AVR microcontroller
2. Raspberry Pi embedded computer
3. EEPROM flash storage
4. Bus buffer
5. Power control circuit
6. Real-Time Clock
7. Magnetometer
8. Manual activation button
A diagram of the WM-Node architecture is shown here:

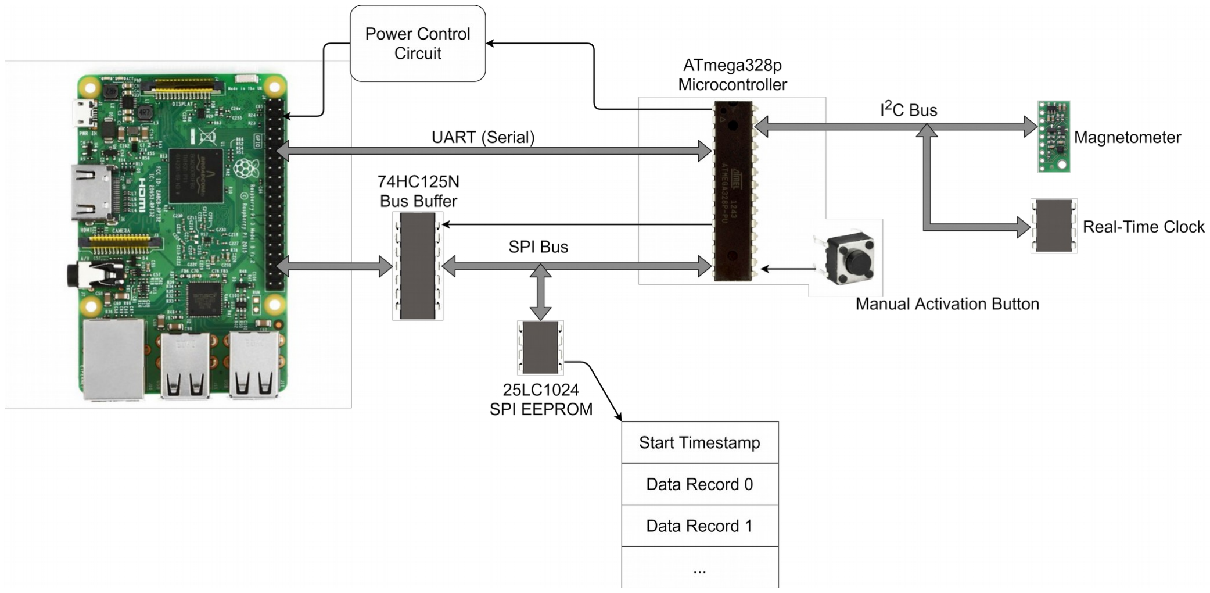
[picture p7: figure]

The more critical components will be described in detail throughout this document. In brief, the microcontroller collects pulse data and stores it on the SPI EEPROM. The Raspberry Pi, when powered by the microcontroller through the power control circuit, reads the pulse data from the EEPROM, processes the data, and stores the data in a file.
The microcontroller and the Raspberry Pi communicate with each other using a UART (serial) connection, not over the SPI bus, which is only used for the EEPROM in this design. Currently, the communication protocol over UART is simple, but may be prone to failure. A more robust communication protocol over UART is being developed.

## AVR Microcontroller

The microcontroller, an ATmega328p from Microchip/Atmel, is an 8-bit AVR core microcontroller, known especially for its use in many Arduino platforms; in fact, a 3.3 V 8 MHz Arduino Pro was used for the prototype.
The microcontroller is primarily responsible for the following tasks:
1. Collect raw data from the magnetometer
2. Detect pulses in the data
3. Store pulses to the EEPROM
4. Control power to the Raspberry Pi
5. Control the Raspberry Pi’s access to the EEPROM
6. Communicate with the Raspberry Pi
- This includes commands to start/stop logging from the user, water flow data, date/time, etc.
7. Generate timestamps using information from the RTC.
Information on the firmware for this device is coming soon.

## Raspberry Pi Embedded Computer

The Raspberry Pi is responsible for processing the data collected by the microcontroller, including disagreggation and storage. The Raspberry Pi will also be responsible for transmitting the data over the internet (via WiFi, cellular, or some other means) to a server.
On top of this technical functionality, the Raspberry Pi also implements a user interface for the datalogger (see the Software Documentation). Settings set by the user are communicated to the microcontroller, and information from the microcontroller is communicated from the microcontroller to the Raspberry Pi and, and then to the user.

## EEPROM Flash Storage

The 25LC1024 SPI EEPROM chip can store 128kB of data from the microcontroller. The data stored in the chip is in the following format:

Bytes 0-2 | Number of data records
Bytes 3-8 | Starting timestamp
Bytes 9-N | Data bytes

## Bus Buffer

The bus buffer is implemented using a 74HC125N buffer chip. The SPI bus on the Raspberry Pi connects to this chip. The chip also connects to the microcontroller’s SPI bus, which connects in turn to the EEPROM chip. This buffer is controlled by the microcontroller. The end result is that when the buffer is activated by the microcontroller, the Raspberry Pi is connected to the EEPROM chip. When the buffer is deactivated by the microcontroller, the Raspberry Pi is disconnected from the EEPROM chip. This permits the SPI bus to be used while the Raspberry Pi is off (driving the I/O pins of the Raspberry Pi while it is powered off can cause damage to the Raspberry Pi).

## Power Control Circuit

The power control circuit switches power on and off to the Raspberry Pi, and is controlled by the microcontroller. The following diagram is from the WM-Node schematic:

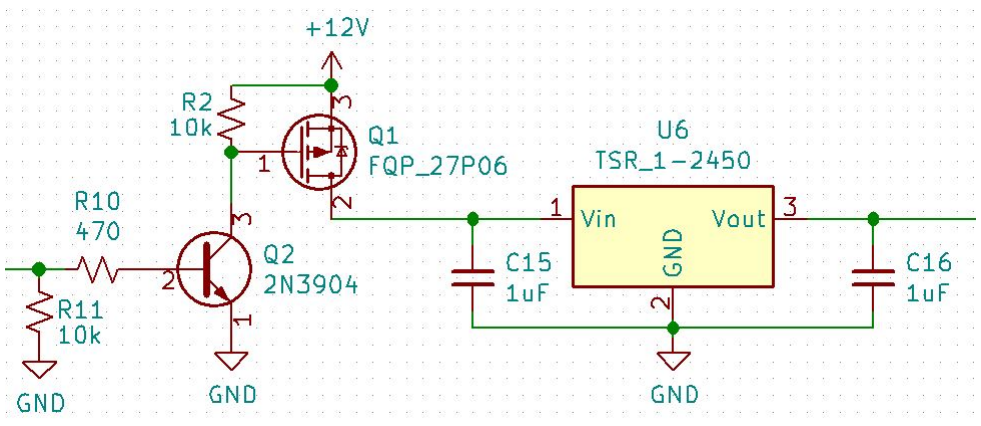
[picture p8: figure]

This looks a bit complicated, but don’t worry, it’s actually quite simple. Start with the voltage regulator, U6. This component converts the battery voltage from 12 volts down to 5 volts for the Raspberry Pi. The two capacitors, C15 and C16, simply smooth out the power supply voltage.
Notice that the transistor Q1 sits between the battery (+12V) and U6. Q1 acts like a switch. When it’s turned on, U6 will output 5 volts. When Q1 is off, U6 will have no input voltage, and will therefore give no output voltage.
To turn Q1 on, the ‘gate’ pin (labeled ‘1’) must be set to 12 volts. To turn Q1 off, the ‘gate’ pin must be set to 0 volts. The microcontroller can set the pin to 0 volts with no issues; however, the microcontroller by itself can only set a pin to 3.3 volts because its supply voltage is 3.3 volts.

To remedy this problem, a second transistor (Q2) is used. Q2 is a different kind of transistor, and works differently than Q1. To turn on Q2, electric current must flow into it through pin 2, the ‘base’ pin. To turn off Q2, no current can flow. This is something the microcontroller can control.
When Q2 is ‘on’, the gate pin on Q1 is connected to zero volts, which ensures that Q1 is ‘off’ and cannot conduct. This then turns off the voltage regulator U6, which turns off the Raspberry Pi. When Q2 is ‘off’, the gate pin of Q1 is no longer connected to zero volts; instead, it is connected to 12 volts through the resistor R2. This allows Q1 to conduct. This turns on the voltage regulator U6, which turns on the Raspberry Pi.

## Magnetometer

The magnetometer used in this prototype is an LIS3MDL magnetometer by ST Microelectronics. The LIS3MDL we use is mounted to a board and sold by Pololu.
The LIS3MDL magnetometer has several configurable sample rates. The sample rate used in this project is 560 Hz (Camilo’s first paper discusses this sampling rate in further depth). When the LIS3MDL signals that data is ready, the data is read by the microcontroller using the I²C serial bus, and is processed and stored on the EEPROM chip.

## Real-Time Clock

The Real-Time Clock (RTC) used in this prototype is a PCF8523 by NXP Semiconductor. This RTC is present on the Arduino Datalogging shield, and was thus a simple prototyping choice for the RTC. The PCF8523 also communicates with the microcontroller using I²C, and shares the I²C bus with the LIS3MDL magnetometer.
The RTC is used by the microcontroller for sample interval timing and timestamp generation. The RTC signals the microcontroller whenever a specified interval has passed, and the microcontroller then counts up the detected pulses and stores that value. The date/time is also read from the RTC when this interval has passed, from which the microcontroller creates a timestamp.

## Manual Activation Button

This button is used to start up the Raspberry Pi manually. This is useful because the Raspberry Pi is turned on and back off about once per day, and it is inconvenient for the user to wait until the Pi turns on to do anything with the Pi. When the button is pressed, the Pi powers on and, instead of automatically turning back off, it will wait for the user to log in. The user can then log in to the system and view files, start/stop a logging session, view water flow data, and other various tasks.

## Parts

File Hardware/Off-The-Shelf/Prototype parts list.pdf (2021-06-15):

Part | Cost ($) | Vendor
12V 10Ah Duracell Battery | 39.99 | Batteries + Bulbs
Raspberry Pi 3B | 35 | Adafruit
Pelican 1150 Waterproof Case (with foam) | 31.96 | Amazon
3.3V, 8MHz Arduino Pro (ATmega328p Board) 15.95 | Sparkfun
Datalogging Shield | 15.95 | Adafruit
Micro SD Card with Adapter | 9.95 | Mouser
5-Conductor Cable | 9.11 | Mouser
TSR_1-2450 Converter | 5.48 | Digikey
LIS3MDL Magnetometer + Breakout Board | 4.95 | Pololu
1725656 Terminal Block | 1.66 | Digikey
1725685 Terminal Block | 4.1 | Digikey
25LC1024-E/SM Connectors | 3.09 | Digikey
Anderson Powerpole Connectors | 2.6 | Amazon
Battery Lead Connectors | 2.75 | Grainger
ATmega328P-AU AVR Microchip | 2.32 | Digikey
Box Kit | 2.1 | Mouser
1920-1076-ND Cable Glands | 1.75 | Digikey
FQP27P06 MOSFET | 1.78 | Digikey
Strap Set: Gear Strapz (+5 Clasps) | 1.52 | Amazon
100NF 50V 0805 Capacitor | 1.5 | Mouser
1uF Ceramic Capacitors | 0.92 | Mouser
Stripboard | 1.43 | Mouser
10k Ohm Resistor | 0.2 | Digikey
4.7k Ohm Resistor | 0.1 | Digikey
In-Line Fuse Holder | 4.21
2N3904 Transistor | 0.44
Spacers | 0.2
Fuse | 0.17
Button | 0.16
Screws | 0.17
Nuts | 0.12 | Mouser
Serial Extender Housing Pack | 0.16 | Pololu
| Total 201.79 | Mouser

Mouser
Mouser
Mouser
Mouser
Mouser

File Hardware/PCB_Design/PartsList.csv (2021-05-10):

Id | Designator | Package | Quantity | Designation | Supplier and ref
1 | JP1 | PinHeader_1x02_P2.54mm_Vertical | 1 | SNT-100-YW-T
2 | U7 | MCP3425 | 1 | MCP3421A0T-ECH
3 | IC2 | 1072 | 1 | 1072
4 | IC1 | SOIC127P600X175-8N | 1 | PCF8523T_1,118
5 | R15,R14 | R_0805_2012Metric_Pad1.15x1.40mm_HandSolder | 2 | 5k
6 | R13 | R_0805_2012Metric_Pad1.15x1.40mm_HandSolder | 1 | 13k
7 | R12 | R_0805_2012Metric_Pad1.15x1.40mm_HandSolder | 1 | 2k
8 | C17,C10,C12 | C_0805_2012Metric_Pad1.15x1.40mm_HandSolder | 3 | 10uF
9 | U5 | SOIC-14_3.9x8.7mm_P1.27mm | 1 | SN74HC125DR
10 | C1,C3,C14,C15,C16 | C_0805_2012Metric_Pad1.15x1.40mm_HandSolder | 5 | 1uF
11 | C2,C5,C8,C9,C11,C13 | C_0805_2012Metric_Pad1.15x1.40mm_HandSolder | 6 | 0.1uF
12 | C4 | C_0805_2012Metric_Pad1.15x1.40mm_HandSolder | 1 | 100uF
13 | C6,C7 | C_0805_2012Metric_Pad1.15x1.40mm_HandSolder | 2 | 20pF
14 | D1,D2,D3 | LED_D3.0mm_Clear | 3 | 151031VS06000
15 | J1 | PinSocket_2x20_P2.54mm_Vertical | 1 | PinSocket_2x20_P2.54mm_Vertical
16 | J2 | TerminalBlock_Phoenix_MPT-0,5-2-2.54_1x02_P2.54mm_Horizontal | 1 | 1725656
17 | J3 | TerminalBlock_Phoenix_MPT-0,5-5-2.54_1x05_P2.54mm_Horizontal | 1 | 1725685
18 | J4 | USB_Micro-B_Molex-105017-0001 | 1 | USB_B_Micro
19 | J5 | PinHeader_2x03_P2.54mm_Vertical | 1 | PinHeader_2x03_P2.54mm_Vertical
20 | Q1 | TO-220-3_Vertical | 1 | FQP27P06
21 | Q2 | TO-92_Inline | 1 | 2N3904
22 | R1,R10 | R_0805_2012Metric_Pad1.15x1.40mm_HandSolder | 2 | 470
23 | R2,R3,R4,R5,R6,R7,R11 | R_0805_2012Metric_Pad1.15x1.40mm_HandSolder | 7 | 10k
24 | R8,R9 | R_0805_2012Metric_Pad1.15x1.40mm_HandSolder | 2 | 1k
25 | SW1,SW2 | SW_PUSH_6mm | 2 | PTS645SL432LFS
26 | SW3 | SW_DIP_SPSTx02_Slide_9.78x7.26mm_W7.62mm_P2.54mm | 1 | 1825057-1
27 | U1 | SOT-23_Handsoldering | 1 | MCP1703AT-3302E/CB
28 | U2 | TQFP-32_7x7mm_P0.8mm | 1 | ATmega328P-AU
29 | U3 | SSOP-28_5.3x10.2mm_P0.65mm | 1 | FT232RL
30 | U4 | SOIJ-8_5.3x5.3mm_P1.27mm | 1 | 25LC1024-E/SM
31 | U6 | Converter_DCDC_TRACO_TSR-1_THT | 1 | TSR_1-2450
32 | Y1 | Crystal_SMD_Abracon_ABM3-2Pin_5.0x3.2mm | 1 | F90800021
33 | Y2 | Crystal_SMD_2012-2Pin_2.0x1.2mm_HandSoldering | 1 | LFXTAL050789REEL

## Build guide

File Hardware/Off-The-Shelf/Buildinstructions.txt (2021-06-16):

Steps to adapt the Adafruit Datalogger Shield (Rev. C) to a 3.3 V Arduino Pro:

	1. Solder Header Pins

	2. Short SCL and SDA jumpers on bottom to connect SCL and SDA to A5 and A4, respectively.
		This is done because the 3.3 V Arduino Pro does not have seperate SCL and SDA pins like a normal Uno.

	3. Short the IOr, 3V, and 5V pads. This connects the I2C pullup resistors to 3.3 V.
		Because the Arduino Pro runs on 3.3 V, the "5V" pad is really at 3.3 V. Note that the datalogger shield does not
		connect with the Arduino Uno 3.3 V output, as it is designed to generate its own.

	4. Remove the 3.3 V Regulator. The system is already supplied with 3.3 V.

	5. Remove the Power LED -- This helps extend battery life.

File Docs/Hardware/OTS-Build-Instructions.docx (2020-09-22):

CIWS-WM-Node

Off-The-Shelf Build Instructions

Hardware ver. 1.0.0

# Overview

  This document covers the construction of a CIWS-WM-Node using mainly off-the-shelf parts. If desired, design files for a printed circuit board solution are included in the repository, and may be used instead. The CIWS-WM-Node built using off-the-shelf parts consists of two main units:
- Data aquisition device
- Computational node

# Data Aquisition Device

The data aquisition device is similar to the CIWS-MWM-Logger device. It is built using an Arduino Pro (Sparkfun part #DEV-10914) development board and a Datalogging Shield (Adafruit part #1141). The following must be soldered on the Datalogging Shield's prototyping area, along with their associated connections to the microcontroller pins:

- EEPROM chip
- 5 position terminal block connector for Magnetometer
- 2 position terminal block connector for 12 V battery power
- Button circuit

The following diagram shows the connections required, including wires to the computational node:

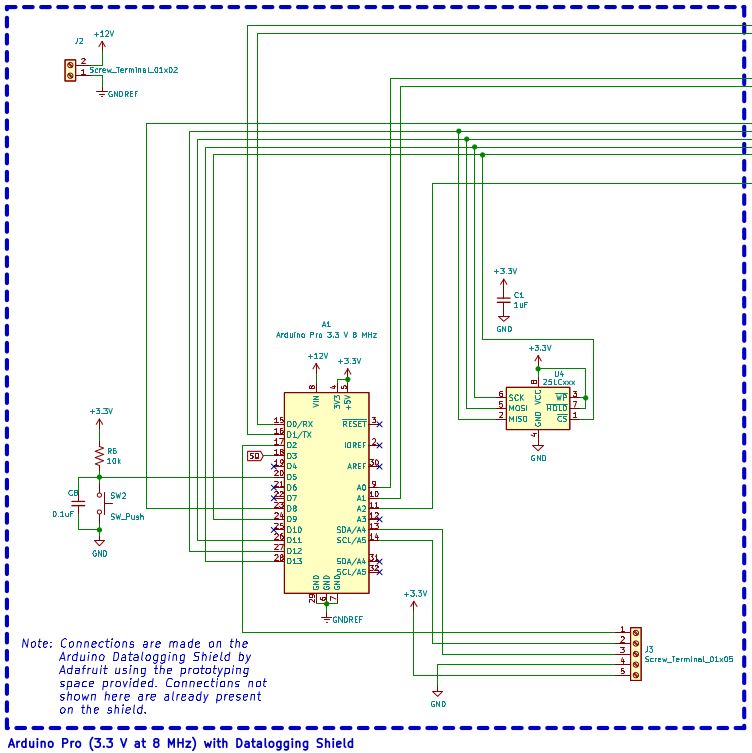
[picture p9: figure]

Along with these connections, the following must also be made:

- Solder the 3V, 5V, and Vio (or IOr) pads together (on the top side of the Datalogging Shield, near the RTC chip)
- Bridge the I²C pads on the underside of the Datalogging Shield, near the analog pin bank.

# Computational Node

The computational node is constructed using a Raspberry Pi 3B and a Perma-Proto HAT (Adafruit part #2310). The following must be soldered onto the Perma-Proto HAT, along with their associated connections to the Raspberry Pi's GPIO pins:

- Bus buffer chip (74HC125)
- Power control circuit
- 5 V regulator
- 2 position terminal block connector for 12 V battery power

The following diagram shows the required connections, including wires to the data aquisition device:

Notice that the symbols used for the bus buffer chip (74HC125) do not include power connections; however, this chip must be connected to 3.3 V and GND in order to function.

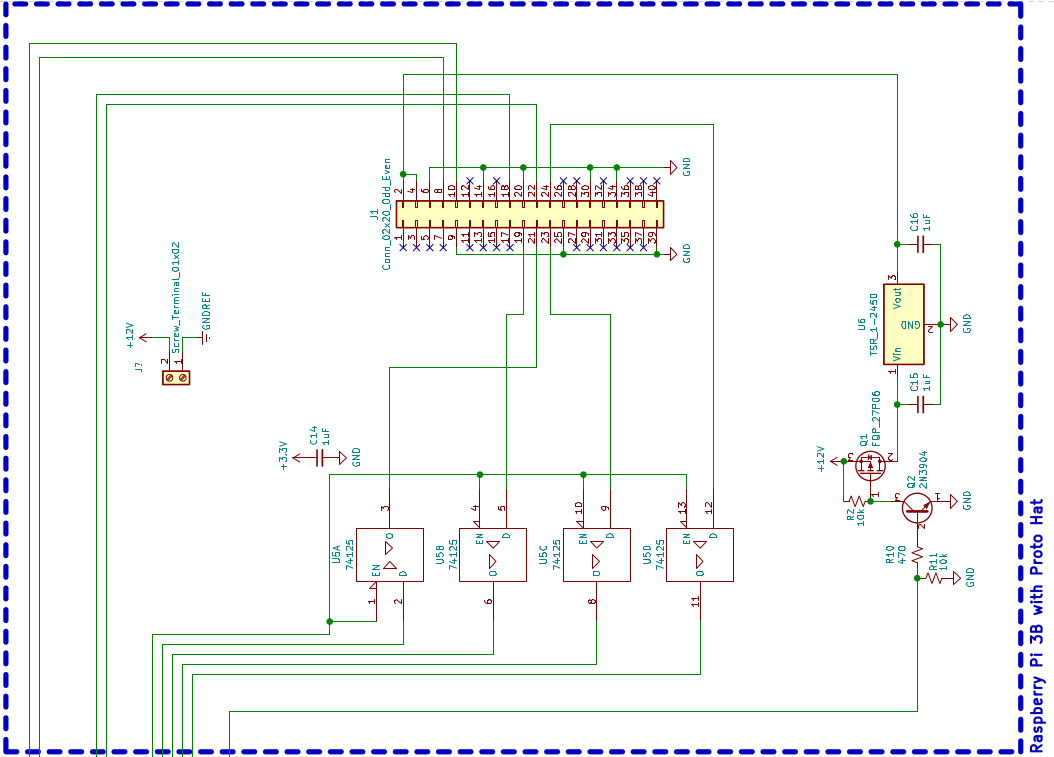
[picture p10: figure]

Unlike the updated design files, our off-the-shelf prototypes do not have an ADC connected for reading the battery voltage. If the ability to read battery voltage is desired, the ADC can be added. The ADC used, MCP3425, only comes in a surface-mount package. For ease of assembly, use a breakout board / development kit for the MCP3425. Connect the ADC board to the Raspberry Pi's I²C bus, and pull the lines up to 3.3 V using resistors. Step down the battery voltage with a voltage divider before the ADC input in order to keep the voltage reading within the ADC's range, and remember the conversion ratio for your software application.

At the end of this document is included the full electrical schematic of the two devices from off-the-shelf parts.

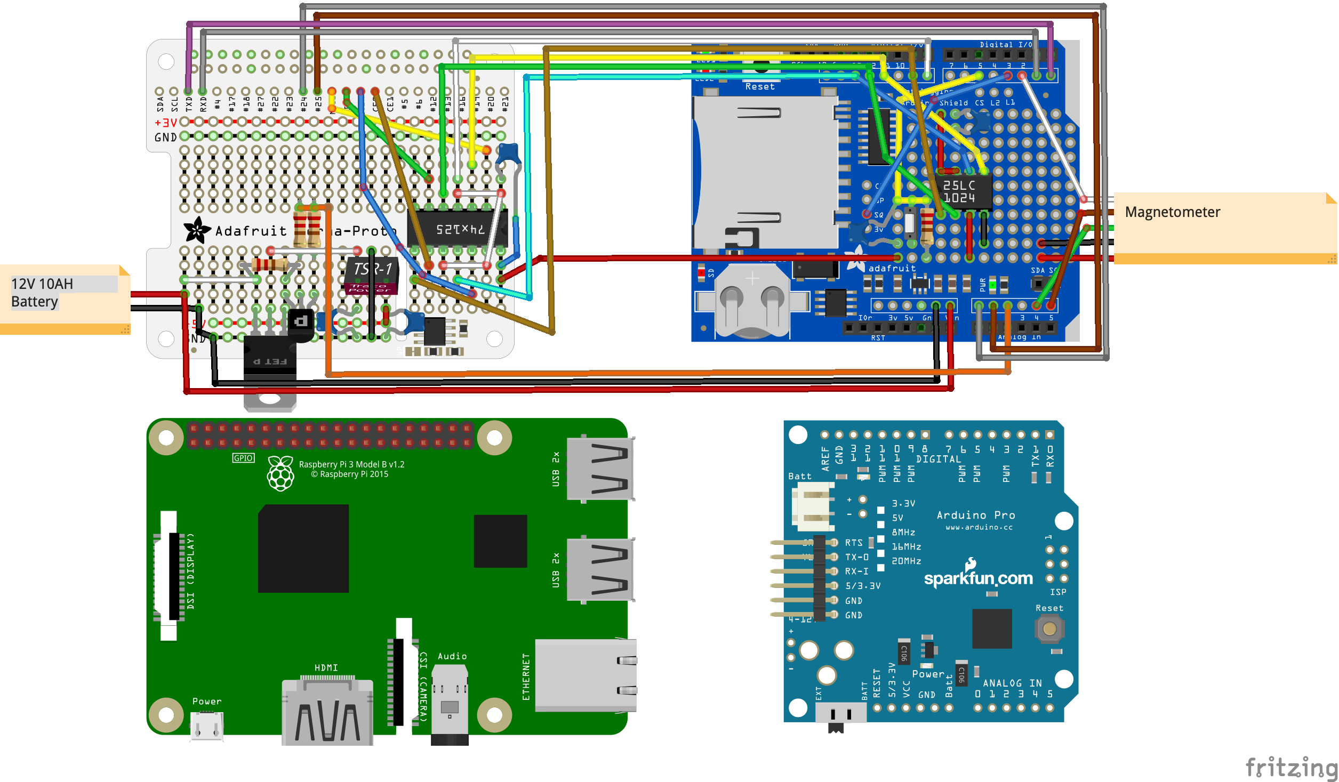
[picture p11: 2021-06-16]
Hardware/Off-The-Shelf/PrototypeWiringGuide.png

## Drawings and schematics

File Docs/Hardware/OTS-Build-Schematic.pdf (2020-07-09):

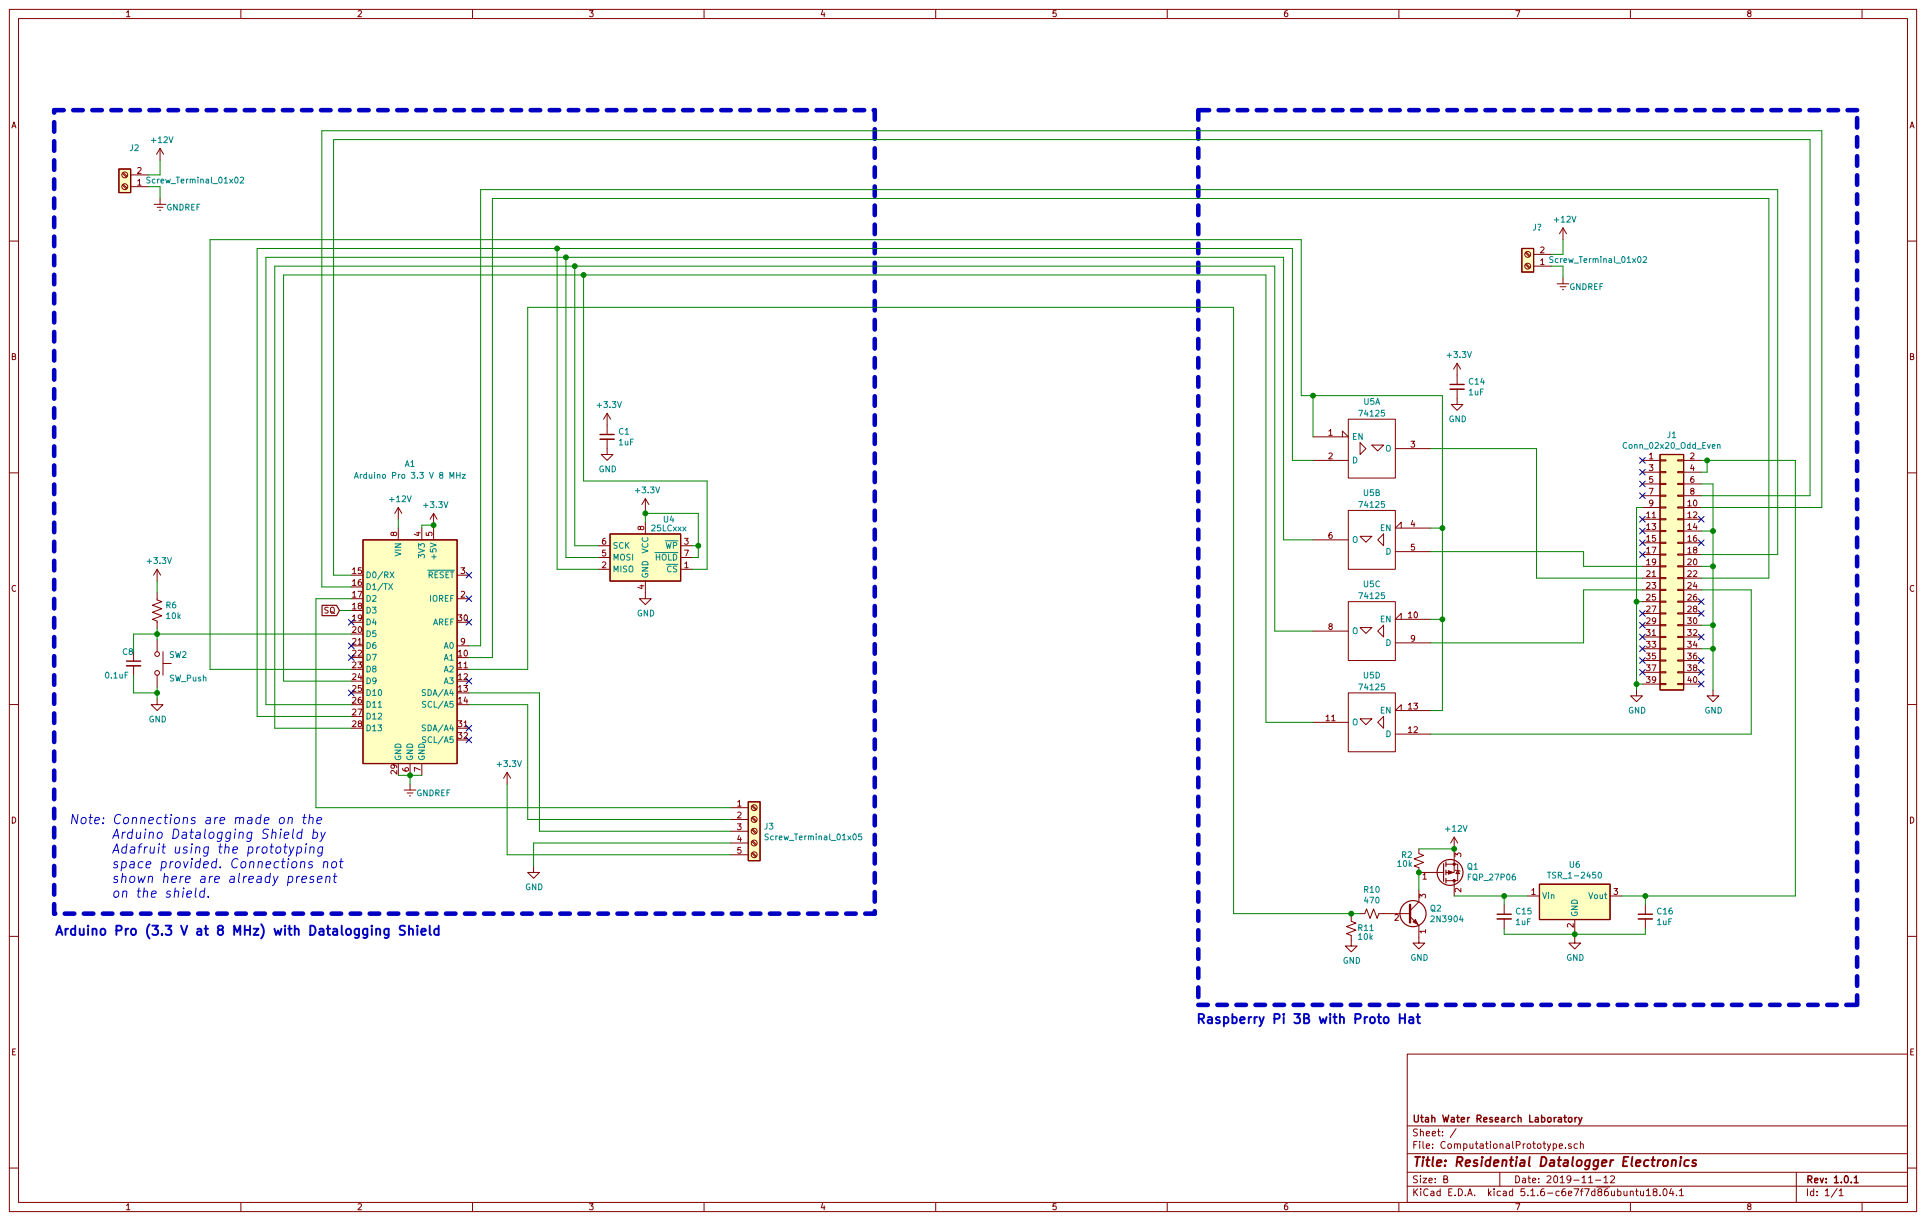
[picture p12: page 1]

4 MOSI 5 SCK 6 HOLD VCC 7

21 | 22
23 | 24

SQ Note: Connections are made on the

Arduino Datalogging Shield by
Adafruit using the prototyping
space provided. Connections not
shown here are already present
on the shield.

Arduino Pro (3.3 V at 8 MHz) with Datalogging Shield

File: ComputationalPrototype.sch Sheet: / Utah Water Research Laboratory R11

Raspberry Pi 3B with Proto Hat

Id: 1/1 Title: Residential Datalogger Electronics

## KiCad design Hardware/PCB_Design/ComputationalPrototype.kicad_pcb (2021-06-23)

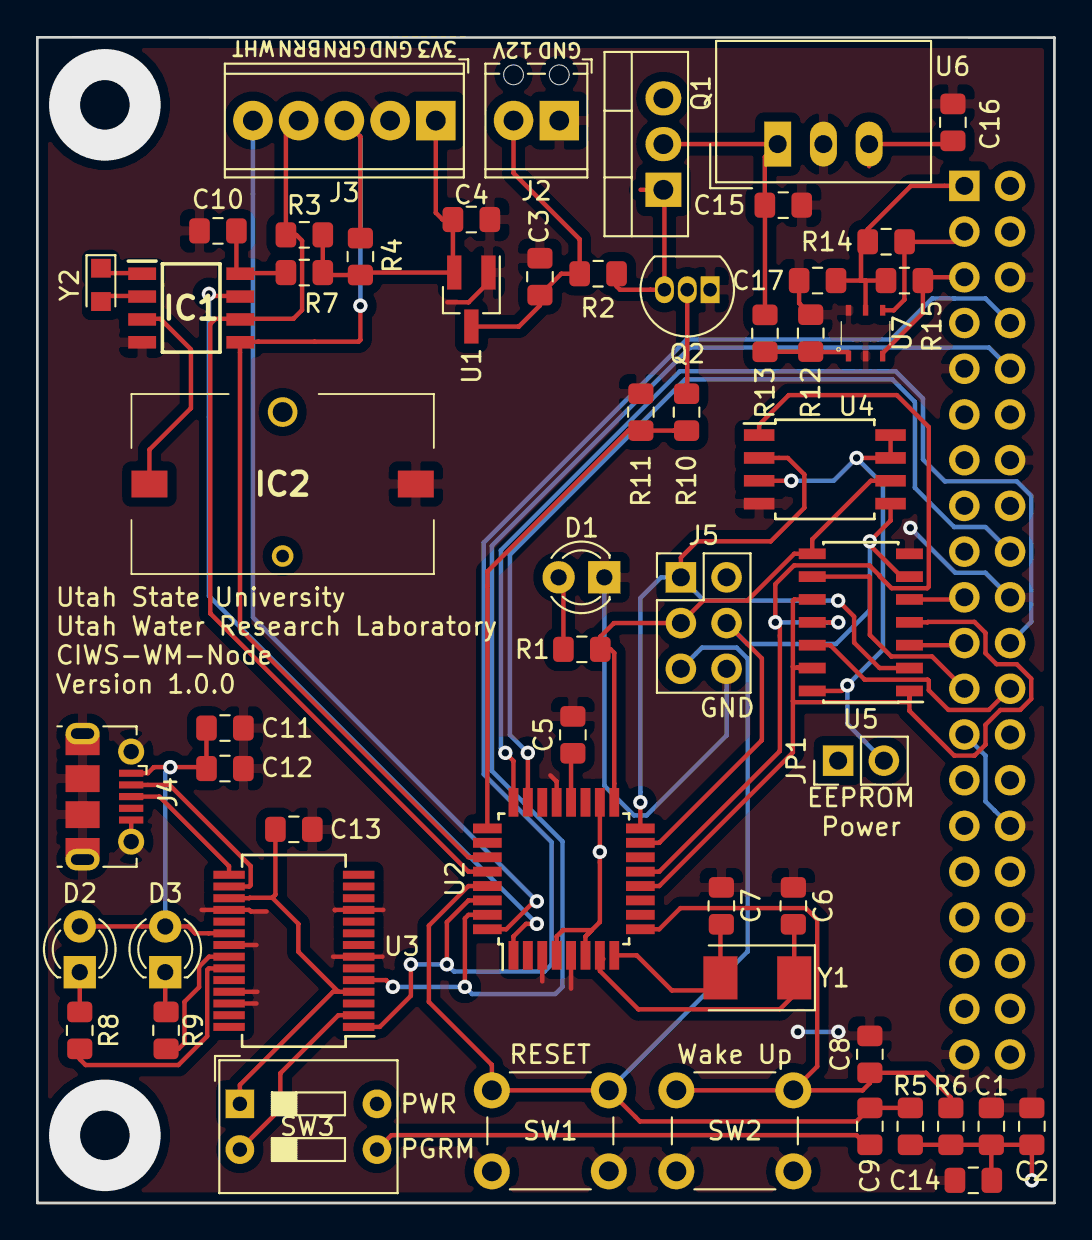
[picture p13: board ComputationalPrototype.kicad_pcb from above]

Board: 2 copper layers, 56.5 x 64.8 mm, 57 parts (1 on the bottom side), 47 nets.

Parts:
C1, C3, C14, C15, C16: 1uF; C_0805_2012Metric_Pad1.15x1.40mm_HandSolder
C2, C5, C8, C9, C11, C13: 0.1uF; C_0805_2012Metric_Pad1.15x1.40mm_HandSolder
C4: 100uF; C_0805_2012Metric_Pad1.15x1.40mm_HandSolder
C6, C7: 20pF; C_0805_2012Metric_Pad1.15x1.40mm_HandSolder
C10, C12, C17: 10uF; C_0805_2012Metric_Pad1.15x1.40mm_HandSolder
D1, D2, D3: 151031VS06000; LED_D3.0mm_Clear
IC1: PCF8523T_1,118; SOIC127P600X175-8N
IC2: 1072
J1: PinSocket_2x20_P2.54mm_Vertical
J2: 1725656; TerminalBlock_Phoenix_MPT-0,5-2-2.54_1x02_P2.54mm_Horizontal
J3: 1725685; TerminalBlock_Phoenix_MPT-0,5-5-2.54_1x05_P2.54mm_Horizontal
J4: USB_B_Micro; USB_Micro-B_Molex-105017-0001
J5: PinHeader_2x03_P2.54mm_Vertical
JP1: SNT-100-YW-T; PinHeader_1x02_P2.54mm_Vertical
Q1: FQP27P06; TO-220-3_Vertical
Q2: 2N3904; TO-92_Inline
R1, R10: 470; R_0805_2012Metric_Pad1.15x1.40mm_HandSolder
R2, R3, R4, R5, R6, R7, R11: 10k; R_0805_2012Metric_Pad1.15x1.40mm_HandSolder
R8, R9: 1k; R_0805_2012Metric_Pad1.15x1.40mm_HandSolder
R12: 2k; R_0805_2012Metric_Pad1.15x1.40mm_HandSolder
R13: 13k; R_0805_2012Metric_Pad1.15x1.40mm_HandSolder
R14, R15: 5k; R_0805_2012Metric_Pad1.15x1.40mm_HandSolder
SW1, SW2: PTS645SL432LFS; SW_PUSH_6mm
SW3: 1825057-1; SW_DIP_SPSTx02_Slide_9.78x7.26mm_W7.62mm_P2.54mm
U1: MCP1703AT-3302E/CB; SOT-23_Handsoldering
U2: ATmega328P-AU; TQFP-32_7x7mm_P0.8mm
U3: FT232RL; SSOP-28_5.3x10.2mm_P0.65mm
U4: 25LC1024-E/SM; SOIJ-8_5.3x5.3mm_P1.27mm
U5: SN74HC125DR; SOIC-14_3.9x8.7mm_P1.27mm
U6: TSR_1-2450; Converter_DCDC_TRACO_TSR-1_THT
U7: MCP3421A0T-ECH; MCP3425
Y1: F90800021; Crystal_SMD_Abracon_ABM3-2Pin_5.0x3.2mm
Y2: LFXTAL050789REEL; Crystal_SMD_2012-2Pin_2.0x1.2mm_HandSoldering

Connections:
+3V3: C1.1, C2.1, C4.1, C14.1, J3.1, J5.2, JP1.1, R3.1, R4.1, R5.1, R6.1, R7.1, SW3.4, U1.2, U2.4, U2.6, U2.18
+5V: C11.1, C12.1, D2.2, D3.2, J4.1, U3.20
+12V: C3.1, J2.2, Q1.3, R2.1, U1.3
GND: C1.2, C2.2, C3.2, C4.2, C5.2, C6.1, C7.1, C8.2, C10.2, C11.2, C12.2, C13.2, C14.2, C15.2, C16.2, C17.1, D1.1, IC1.4, IC2.2, J1.6, J1.9, J1.14, J1.20, J1.25, J1.30, J1.34, J1.39, J2.1, J3.2, J4.5, J4.6, J5.6, Q2.1, R11.1, R12.1, SW1.2, SW2.2, U1.1, U2.3, U2.5, U2.21, U3.7, U3.11, U3.18, U3.21, U3.25, U3.26, U4.4, U5.7, U6.2, U7.2, U7.6
unnamed: C5.1, U2.20
unnamed: C6.2, U2.7, Y1.1
unnamed: C7.2, U2.8, Y1.2
unnamed: C8.1, R6.2, SW2.1, U2.9
unnamed: C9.1, SW3.3
unnamed: C9.2, J5.5, R5.2, SW1.1, U2.29
unnamed: C10.1, IC1.8, R7.2
unnamed: C13.1, SW3.1, U3.4, U3.17
unnamed: C15.1, Q1.2, R13.2, U6.1
unnamed: C16.1, J1.2, J1.4, U6.3
unnamed: C17.2, J1.1, R14.1, R15.1, U7.5
unnamed: D1.2, R1.2
unnamed: D2.1, R8.1
unnamed: D3.1, R9.1
unnamed: IC1.3, IC2.1
unnamed: J1.3, R14.2, U7.4
unnamed: J1.5, R15.2, U7.3
unnamed: J1.8, U2.30, U3.1
unnamed: J1.10, U2.31, U3.5
unnamed: J1.18, U2.23
unnamed: J1.19, U5.5
unnamed: J1.21, U5.3
unnamed: J1.22, U2.24
unnamed: J1.23, U5.9
unnamed: J1.24, U5.12
unnamed: IC1.5, J3.3, R4.2, U2.27
unnamed: IC1.6, J3.4, R3.2, U2.28
unnamed: J3.5, U2.32
unnamed: J4.2, U3.16
unnamed: J4.3, U3.15
unnamed: J5.1, U2.16, U4.2, U5.2
unnamed: J5.3, R1.1, U2.17, U4.6, U5.8
unnamed: J5.4, U2.15, U4.5, U5.6
unnamed: Q1.1, Q2.3, R2.2
unnamed: Q2.2, R10.1
unnamed: R8.2, U3.23
unnamed: R9.2, U3.22
unnamed: R10.2, R11.2, U2.25
unnamed: R12.2, R13.1, U7.1
unnamed: SW3.2, U3.2
unnamed: U2.12, U5.1, U5.4, U5.10, U5.13
unnamed: U2.13, U4.1, U5.11
VCC: JP1.2, U4.3, U4.7, U4.8, U5.14

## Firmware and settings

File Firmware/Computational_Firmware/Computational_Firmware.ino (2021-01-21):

// Firmware for the CIWS Residential Datalogger
// Arduino IDE ver. 1.8.9
// Utah Water Research Lab
// Updated: 9/12/2019
// Daniel Henshaw and Josh Tracy

/*****************************************************************************************************************\
* Hardware Description
*  ___________________   GPIO     Power Enable                                  |__Power
* |                   |------------------------------------------------------->|___|---
* |                   |                                                                |
* |                   |  TWI          ___                                              |_______________________
* |                   |<------------>[___] RTC                                         |                       |
* |                   |      |        ___                                              |                       |
* |                   |       ------>|___| Sensor                                      |                       |
* |                   |  GPIO                                   Enable                 |                       |
* |                   |------------------------------------------------->|         SPI |                       |
* |                   |                                 <---------------|><|---------->|          Host         |
* |                   |  SPI                           |   ___        Tri-State Buff   |        Computer       |
* |                   |<--------------------------------->|___| EEPROM                 |                       |
* |                   |<-----[] Activate Button                                        |                       |
* |___________________|  GPIO                                                          |                       |
*  Controller    | Serial                                                       Serial |                       |
*                 <------------------------------------------------------------------->|                       |
*                                                                                      |                       |
*                                                                                      |                       |
*                                                                                      |_______________________|
*
* Serial:          Serial interface for data swapping between Controller and Host Computer
* Controller:      Arduino Pro/Pro Mini (Note: Few if any Arduino Libraries used, in order to boost performance)
* Host Computer:   Raspberry Pi. Runs data processing algorithms on data collected from Controller.
* EEPROM:          Electrically Erasable Programmable Read-Only Memory -- Stores data logged by Controller
* Activate Button: Button to power up the Host Computer manually.
* Sensor:          LIS3MDL Magnetometer to detect magnetic signal from water register
* RTC:             Real Time Clock to track time and initialize new data sample every four seconds.
* Power Enable:    Enable signal controls Host Computer's connection to power (NOTE: does not power Host Computer)
\*****************************************************************************************************************/

/*****************************************************************\
* Software Description
* Overview:
*   User inputs:
*     Activation Button.
*   Device inputs:
*     Magnetometer Sensor
*     Real Time Clock
*     Serial Reports
*   Device outputs:
*     Data Records
*     Serial Reports
*     Power Control for host computer
*
* Structure:
*   1. Setup
*   2. Handle Raspberry Pi Power-up (for start-up configuration)
*   3. Loop
*        If Raspberry Pi is on
*          Handle Raspberry Pi
*        If Four Seconds has passed
*          Load date/time
*          If logging
*            If EEPROM Free
*              Store new record on EEPROM
*            Else
*              Store new record in RAM Buffer
*        If Magnetometer data ready
*          Read the magnetometer data
*          If peak detected
*            pulseCount += 1
*      Repeat Loop
*
* Interrupts:
*   1. INT0_ISR()
*
*   2. INT1_ISR()
*
\*****************************************************************/

#include "powerSleep.h"
#include "state.h"
#include "RTC_PCF8523.h"
#include "storeNewRecord.h"
#include "detectPeaks.h"
#include "magnetometer.h"
#include "storeNewRecord.h"
#include "comm.h"

#define BUFFER_MAX 24000

#define START 0xEE

volatile State_t State;                       // System State structure
volatile Date_t Date;                         // System Time and Date structure
volatile Date_t Date_Snapshot;
volatile SignalState_t SignalState;           // Struct containing signal data from magnetometer
volatile unsigned char report[REPORT_SIZE];   // Array containing system information. The report is passed between the microcontroller and the host computer (designed for a Raspberry Pi)
volatile char reportIndex = 0;                // current index of the above report
bool countDown = false;                       // Tells program to count every four seconds until it's time to power off the host computer.
char powerOff_Count = 0;                      // Stores the count as described above.
byte current_day = 0;
unsigned long keepup = 0;

void setup()
{
  Serial.begin(9600);
  DDRB |= 0x01;                                   // Pin B0 (Digital pin 8) set as output (the rest of GPIO B is taken care of by SPI initialization)
  PORTB |= 0x01;                                  // Set enable pin to host computer bus buffer high (active low, keeps host computer disconnected until powered on).

  DDRD = 0xD3;                                    // Input Pins: 0, 1, 2, 3, 5;     Output Pins: 4, 6, 7;
  PORTD |= 0x88;                                  // Pullup on Pin 3, Set Pin 7 HIGH;

  DDRC = 0x04;                                    // Input Pins: A0, A1;            Output Pins: A2;
  PORTC = 0x00;                                   // A0 and A1 have no pullups, A2 starts low (keeps host computer off)

  resetState(&State);                             // Set up the System State structure

  mag_init();                                     // Initialize Magnetometer
  spiInit();                                      // Initialize SPI Module

  rtcTransfer(reg_Tmr_CLKOUT_ctrl, WRITE, 0x3A);  // Setup RTC Timer
  rtcTransfer(reg_Tmr_A_freq_ctrl, WRITE, 0x02);
  rtcTransfer(reg_Tmr_A_reg, WRITE, State.interval);
  rtcTransfer(reg_Control_2, WRITE, 0x02);
  rtcTransfer(reg_Control_3, WRITE, 0x80);

  attachInterrupt(digitalPinToInterrupt(2), INT0_ISR, RISING);   // Setup Interrupts
  attachInterrupt(digitalPinToInterrupt(3), INT1_ISR, FALLING);
  EIMSK &= ~(1 << INT0);                                        // Disable Sensor interrupt
  EIMSK |= (1 << INT1);                                         // Enable 4-Second RTC interrupt.

  loadDateTime(&Date);            // Load date and time into the Date structure
  current_day = Date.days;
  report[0] = Date.years;         // Initialize report data:  // Years
  report[1] = Date.months;                                    // Months
  report[2] = Date.days;                                      // Days
  report[3] = Date.hours;                                     // Hours
  report[4] = Date.minutes;                                   // Minutes
  report[5] = Date.seconds;                                   // Seconds
  report[6] = 0;                                              // Pulses in last period
  report[7] = 0;                                              // Total pulses (byte 0)
  report[8] = 0;                                              // Total pulses (byte 1)
  report[9] = 0;                                              // Total pulses (byte 2)
  report[10] = 0;                                             // Logging (y/n = 1/0)
  report[11] = 4;                                             // Time between logged samples (default = 4 seconds)
  
  sei();                          // Enable interrupts
  disableUnneededPeripherals();   // Disable peripherals not in use (WARNING: FUNCTION MUST NOT DISABLE TIMERS)
}

void loop()
{
  if((((PIND & 0x20) == 0x00) && !State.RPiON) || // If button is pressed and host computer is off
    (current_day != Date.days) ||                 // OR it's a new day
    (State.romAddr > (BUFFER_MAX + HEADER_SIZE))) // OR The ROM address is greater than the max data length
  {
    current_day = Date.days;
    State.RPiON = true;                                                               // Let the rest of the program know that the host computer is on
    copyDateTime(&Date, &Date_Snapshot);                                              // Get a timestamp for the data to be put in the ROM buffer
    State.romAddr = HEADER_SIZE;                                                      // Reset the ROM address
    State.romFree = false;                                                            // Let the rest of the program know that the EEPROM chip is not accessible
    writeDataSize(&State);                                                            // Store the number of data bytes in the first three bytes of the EEPROM chip for the host computer
    powerRPiON();                                                                     // Power on the host computer
    keepup = millis();
  }

  if(State.RPiON)                     /** Execute the following code IF the host computer is on **/
  {
    if(State.newReport)                   // If a new report has been exchanged between the microcontroller and the host computer
    {
      State.newReport = false;              // Let the rest of the program know that the new report has been serviced
      updateReport(report, &Date, &State);  // Service the new report by updating state, date, and time information.
    }

    if(usartReceiveComplete())            // If the microcontroller has received a byte from the host computer
    {
      unsigned char temp = UART_Receive();  // Store new byte

      if(temp == START)      // If new byte is an unescaped START
      {
        for(int i = reportIndex; i < REPORT_SIZE; i++)
        {
          report[i] = 0xFF;
        }
        reportIndex = 0;                                // reset reportIndex
        State.newReport = true;
      }
      else
      {
        UART_Transmit(report[reportIndex]);   // Transmit next byte
        report[reportIndex] = temp;           // Update the current report byte with the newly received byte
        if((++reportIndex) >= REPORT_SIZE)    // If the report has been filled up
        {
          reportIndex = 0;                      // Reset the report index
          State.newReport = true;               // Let the rest of the program know that a new report is ready to be serviced
        }
      }
    }

//    if(((PINC & 0x01) == 0x01) && State.romFree)
//      State.romFree = false;

    if(((PINC & 0x01) == 0x00) && !State.romFree && State.powerGood && ((millis() - keepup) > 17000))  // If the EEPROM Busy signal from the host computer goes low when the host computer has been detected as ON and reading the EEPROM
    {
      State.romFree = true;                                             // Let the rest of the program know that the EEPROM is accessible
      PORTB |= 0x01;                                                    // Set the host computer's SPI bus enable line high (active low, so the host computer is disconnected).
      spiInit();                                                        // Set the microcontroller's SPI pins appropriately again.
    }

    if(((PINC & 0x02) == 0x02) && !State.powerGood)   // If the host computer's power good line transitions from low to high
      State.powerGood = true;                           // Let the rest of the program know that the host computer is successfully powered on.

    if(((PINC & 0x02) != 0x02) && State.powerGood)    // If the host computer's power good line transitions from high to low
    {
      State.powerGood = false;                          // Let the rest of the program know that the host computer is shutting down
      countDown = true;                                 // Tell the rest of the program to count every four seconds to know when to disconnect power to the host computer
      powerOff_Count = 0;                               // Initialize the counter.
    }

    if(powerOff_Count > (12 / State.interval))          // If the count exceeds 12 seconds (Note, this is VERY rough)
    {
      powerOff_Count = 0;                               // Reset the counter
      countDown = false;                                // Let the rest of the program know that it is know longer counting
      powerRPiOFF();                                    // Disconnect power to the host computer
      State.RPiON = false;                              // Let the rest of the program know that the host computer has been powered off
    }

    if(State.RPiFalseON)                              // If a certain amount of time passes and the host computer is not freeing up the EEPROM
    {
      State.romFree = true;                             // Let the rest of the program know that the EEPROM chip is now accessible
      State.RPiFalseON = false;
      PORTB |= 0x01;                                    // Disable the host computer's SPI bus
      spiInit();                                        // Set the microcontroller's SPI pins appropriately again.
      powerRPiOFF();                                    // Disconnect power to the host computer
      State.RPiON = false;                              // Let the rest of the program know that the host computer is no longer on
      State.powerGood = false;                          // Let the rest of the program know that the host computer is no longer on
    }
  }

  // DANIEL
  /*****************************************\
  * 4-second update: Update at 4 seconds
  * If 4-second flag is set:
  *   Store a new record
  \*****************************************/
  if(State.flag4)                                     // If four seconds have passed
  {
    State.flag4 = 0;                                    // Reset flag4 to zero
    rtcTransfer(reg_Control_2, WRITE, 0x02);            // Reset real time clock interrupt flag
    loadDateTime(&Date);                                // Update the date and time from the real time clock
    report[0] = Date.years;                             // Sync report date/time with RTC date/time
    report[1] = Date.months;
    report[2] = Date.days;
    report[3] = Date.hours;
    report[4] = Date.minutes;
    report[5] = Date.seconds;
    if(State.logging)                                   // If the microcontroller is logging data
    {
      storeNewRecord(&State, &Date, &Date_Snapshot);    // Store a new record
      report[6] = State.lastCount;                      // Store counted pulses from the previous sample period in report
      report[7] = (State.totalCount >> 16) & 0xFF;      // Store counted pulses over the entire logging period in report
      report[8] = (State.totalCount >> 8) & 0xFF;
      report[9] = State.totalCount & 0xFF;
    }
    if(countDown)                                       // If it's time to count to the host computer's shutdown time
      powerOff_Count += 1;                                // Increment the counter
  }

  // JOSH
  /*****************************************\
   * Read Magnetometer:
   *
   * If readMag is set:
   *   call readData(&mag, &SignalState);
   *   If peakDetected(&SignalState)
   *     State.pulseCount += 1;
  \*****************************************/
  if(State.readMag)                                   // If new data is ready from the magnetometer
  {
    State.readMag = false;                              // Let the rest of the program know that the new data is being read
    readData(&SignalState);                             // Read the data from the magnetometer and store it in the SignalState struct

    bool peak = peakDetected(&SignalState);             // Process the data in order to detect peaks

    if(peak)                                            // If a peak was detected
    {
      State.pulseCount += 1;                              // Increment the current pulse count
    }
  }
}

// DANIEL
/* Function Title: INT0_ISR()
 *
 * Friendly Name:  Sensor Interrupt Service Routine (ISR)
 *
 * Description: sets readMag flag to true every time this function is
 *              called by hardware.
 */
void INT0_ISR()
{
  State.readMag = true;
}

// DANIEL
/* Function Title: INT1_ISR()
 *
 * Friendly Name:  Real Time Clock OUT Interrupt Service Routine (ISR)
 *
 * Description: sets the 4-second flag to true each time this function
 *              is called by hardware. The Real Time Clock generates
 *              the signal that calls this ISR once every four seconds.
 */
void INT1_ISR()
{
  State.flag4 = true;     // sets the "four second flag" to true
}

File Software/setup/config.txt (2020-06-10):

# For more options and information see
# http://rpf.io/configtxt
# Some settings may impact device functionality. See link above for details

# uncomment if you get no picture on HDMI for a default "safe" mode
#hdmi_safe=1

# uncomment this if your display has a black border of unused pixels visible
# and your display can output without overscan
#disable_overscan=1

# uncomment the following to adjust overscan. Use positive numbers if console
# goes off screen, and negative if there is too much border
#overscan_left=16
#overscan_right=16
#overscan_top=16
#overscan_bottom=16

# uncomment to force a console size. By default it will be display's size minus
# overscan.
#framebuffer_width=1280
#framebuffer_height=720

# uncomment if hdmi display is not detected and composite is being output
#hdmi_force_hotplug=1

# uncomment to force a specific HDMI mode (this will force VGA)
#hdmi_group=1
#hdmi_mode=1

# uncomment to force a HDMI mode rather than DVI. This can make audio work in
# DMT (computer monitor) modes
#hdmi_drive=2

# uncomment to increase signal to HDMI, if you have interference, blanking, or
# no display
#config_hdmi_boost=4

# uncomment for composite PAL
#sdtv_mode=2

#uncomment to overclock the arm. 700 MHz is the default.
#arm_freq=800

# Uncomment some or all of these to enable the optional hardware interfaces
dtparam=i2c_arm=on
#dtparam=i2s=on
dtparam=spi=on

# Uncomment this to enable infrared communication.
#dtoverlay=gpio-ir,gpio_pin=17
#dtoverlay=gpio-ir-tx,gpio_pin=18

# Additional overlays and parameters are documented /boot/overlays/README

# Enable audio (loads snd_bcm2835)
dtparam=audio=on

[pi4]
# Enable DRM VC4 V3D driver on top of the dispmanx display stack
dtoverlay=vc4-fkms-v3d
max_framebuffers=2

[all]
#dtoverlay=vc4-fkms-v3d
enable_uart=1
core_freq=250

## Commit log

2019-12-16 Fixed firmware bugs
    Missing data records
    Incorrect timestamps
    [Computational_Firmware.ino, RTC_PCF8523.cpp, comm.cpp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]
2020-05-14 Changed Raspberry Pi power-on logic: will power on every new day to chunk data files by day
2020-05-18 Fixed powerSleep issues
2020-05-19 Fixed bug: ROM data buffer index may go out of bounds
    [storeNewRecord.cpp]
2020-05-20 Fixing auto turn-off condition
    [LoggerAutoRun.py]
2020-05-20 Attempting to fix issue #1
    [LoggerAutoRun.py]
2020-06-10 Merging develop into master branch
    [ComputationalPrototype.kicad_pcb, ComputationalPrototype.sch, config.txt]
2020-08-07 Added settings for determining which datasets to store on the device
